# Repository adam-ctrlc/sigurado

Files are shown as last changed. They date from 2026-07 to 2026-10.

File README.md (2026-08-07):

# Sigurado

**Two scans. One person. No mystery.**

Sigurado is a dual-biometric access and materials accountability system for a school
laboratory stockroom. A fingerprint at the door opens a short window; the cabinet then
opens only for that same person, while that window is still live. Everything is recorded
with an identity, a reader, and a server timestamp, and shown on a live web console.

The name is Filipino for "sure", which is the point: at any moment you can say who opened
the cabinet and what they took.

---

## Why it works this way

Most fingerprint locks answer one question: is this a registered finger? That still lets a
stranger walk in behind somebody and open the cabinet a minute later. Sigurado answers a
harder one: **is this the person who just came through the door?**

1. **Scan at the door.** The lock releases and a timed window opens, belonging to one
   person.
2. **Scan at the cabinet, inside that window.** The reader checks that the finger it just
   read belongs to the person the door let in. Anything else is refused and recorded as a
   tailgating attempt.
3. **Record what you took.** The cabinet shows a one-time code on its screen as it opens.
   The website will not accept a checkout without that code, so a written record always
   corresponds to a real, physical opening.

The system separates two kinds of fact and never confuses them. **Reader events** come
from the hardware and cannot be edited by anyone, including an administrator.
**Checkouts** are claims typed in by a person, trustworthy only because they require the
code from the opening. The gap between the two is where the interesting questions live,
which is what the flags page is for.

## What it does

- **Sequential dual biometrics.** Door then cabinet, with a session that belongs to one
  person and expires on its own.
- **Enrollment with claiming.** A reader captures a fingerprint and shows a one-time code.
  The finger belongs to nobody until somebody enters that code on the website, so a
  template can never be silently bound to the wrong account.
- **Materials checkout.** An item and quantity table, an optional photo, and the cabinet's
  code as proof the opening happened.
- **Live audit trail.** Every scan, unlock, refusal and enrollment, streamed over
  server-sent events, searchable and filterable from the address bar.
- **Flags.** Eleven checks run over the trail and surface what does not add up: an opening
  with no record behind it, tailgating, guessed checkout codes, unregistered fingers tried
  repeatedly, openings outside lab hours, disabled accounts still trying, readers that have
  gone quiet, enrollment codes nobody ever claimed, and more.
- **Sheet.** The whole trail as a spreadsheet, with lettered columns, numbered rows, a
  frozen header and CSV export. Optionally mirrored to Google Sheets.
- **SMS alerts.** A SIM800L on the cabinet node sends a text when the cabinet opens or
  access is refused. The server queues; the node sends.
- **Roles.** Students see their own records, faculty see everything and change nothing,
  administrators run the room. An administrator cannot disable, delete or demote
  themselves.
- **Guides.** Numbered, step-by-step instructions built into the app for each role.

## Repository layout

```
backend/     Rust API: axum 0.8, SeaORM 1.1, SQLite, JWT, argon2
frontend/    SvelteKit 2 + Svelte 5 runes, Tailwind CSS v4, shadcn-svelte
esp32/       Firmware for both reader nodes (Arduino, ESP32 DevKit v1)
visualize/   Parametric OpenSCAD model of the cabinet and the scanner enclosure
```

## Hardware

Two ESP32 nodes, one at the door and one on the cabinet. Nothing exotic.

| Part | Notes |
| --- | --- |
| ESP32 DevKit v1, 30-pin | One per node. PSRAM and JTAG disabled in the IDE. |
| R307 or AS608 fingerprint sensor | One per node, on UART2. Templates live on the sensor. |
| 16x2 I2C LCD | Prompts, and the checkout code on the cabinet node. |
| Relay plus 12V solenoid | Fail-secure; the coil never runs off the ESP32 rails. |
| Lever limit switch | Reports whether the door is really shut. Debounced in firmware. |
| SIM800L | Cabinet node only, on UART1, with its own 4V supply. |
| Buzzer, LED, push button | Enrollment and the door-left-open reminder. |

Wiring for each node is documented at the top of its sketch. Matching is done on the
sensor itself, so slot numbers are local to a reader; that is why a person enrolls at the
door and at the cabinet separately, and why finger tokens are namespaced per device.

If the door node cannot reach the router, the cabinet node can share its connection:
set `SHARE_WIFI` in the cabinet config and point the door node at its SSID.

## Running it

### Backend

```bash
cd backend
cp .env.example .env          # then fill in DATABASE_URL and JWT_SECRET
cargo run -p migration -- up  # migrations do not run at startup
cargo run --bin seed          # creates the first administrator
cargo run --bin backend
```

Listens on `127.0.0.1:8080` by default. The SQLite file lives in `backend/db/`,
which is where `.env.example` points and the only place worth backing up. The
server creates that folder if it is missing, so pointing `DATABASE_URL` somewhere
new needs no `mkdir` first.

### Frontend

```bash
cd frontend
pnpm install
pnpm dev
```

Serves on `localhost:5173` and expects the API at `localhost:8080`.

### Firmware

Open `esp32/door/door.ino` or `esp32/cabinet/cabinet.ino` in the Arduino IDE. Board:
**ESP32 Dev Module**. Libraries: Adafruit Fingerprint Sensor Library, LiquidCrystal I2C,
ArduinoJson v7. Pair each node from **Devices** in the web app, then paste the device id
and secret it gives you into `src/Config.h`. The secret is shown once.

Both sketches compile clean against esp32 core 3.3.11, at roughly 81% of the default
1.2MB app partition.

## Configuration

All backend settings live in `backend/.env`; see `.env.example`. Notable ones:

| Variable | Default | What it does |
| --- | --- | --- |
| `SESSION_TTL_SECS` | 120 | How long the door window stays open. |
| `ENROLL_CODE_TTL_SECS` | 300 | Life of an enrollment code. |
| `LAB_UTC_OFFSET_HOURS` | 8 | The room's clock, used for after-hours checks and dates. |
| `SHEETS_ENABLED` | false | Optional mirror of the trail into Google Sheets. |

Values containing spaces must be quoted. Anything after an unquoted space is silently
dropped by the parser, which is a good way to lose an afternoon.

## Security notes

- Passwords are hashed with argon2. The policy is 8 to 16 characters with an upper, a
  lower and a symbol, enforced in the backend and mirrored in the UI.
- Readers authenticate with a device id and secret pair, never a user token, so a stolen
  reader cannot impersonate a person. Secrets can be rotated from the web app.
- Fingerprint templates never leave the sensor. The server only ever sees an opaque token.
- Reader events cannot be edited or deleted through the API by anyone. A wrong record is
  corrected by adding the right one.
- `.env` files, the database, and uploaded photos are excluded from version control. Every
  credential in the repository is a placeholder.

## Status

Backend, frontend and firmware are complete and build clean, with the backend test suite
and `svelte-check` passing. The firmware compiles for the ESP32 but has not been run on
assembled hardware yet, so treat pin assignments and timings as correct-but-unproven until
you have flashed a board. The SMS and Google Sheets paths were verified end to end against
local stand-ins rather than a real modem or a real Google account.

## License

Apache License 2.0. See [LICENSE](LICENSE).

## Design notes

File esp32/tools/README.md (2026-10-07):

# Tools

Double-click the `.cmd` files. Each one is a thin wrapper that runs the matching
PowerShell script in `scripts/` with the execution policy bypassed for that one
call, so nothing has to be changed machine wide.

| File | What it does |
|---|---|
| `Find-Board.cmd` | Lists the boards it can see and says why each port was picked |
| `Upload-Door.cmd` | Compiles and flashes `door/` |
| `Upload-Cabinet.cmd` | Compiles and flashes `cabinet/` |
| `Monitor-Door.cmd` | Serial monitor on the door node |
| `Monitor-Cabinet.cmd` | Serial monitor on the cabinet node |

Both uploaders take an optional sketch name to send one of the component tests
in `testing/` instead of the firmware:

```
Upload-Door.cmd fingerprint
Upload-Cabinet.cmd limit_switch
```

## Finding the right board

You never type a COM number. `Find-Board.ps1` reads the USB vendor and product
id behind every serial port and only considers the chips an ESP32 board actually
uses: CP210x, CH340, CH9102, FTDI, and Espressif's own native USB. A laptop with
a paired phone has two or three Bluetooth COM ports that look like boards to
anything that only counts ports, and those are excluded.

The door and cabinet nodes are the same hardware, so USB cannot tell them apart.

- One board plugged in: it is taken as whichever node you asked for.
- Two plugged in, and one already known: the other is deduced, no question asked.
- Two plugged in and neither known: you are asked once, and the answer is saved
  in `scripts/nodes.json` against the board's USB instance id, so it survives
  Windows renumbering the ports.

`nodes.json` is local to your machine and is not committed. Delete it, or run
`scripts\Find-Board.ps1 -Node door -Forget`, to be asked again.

## Requirements

`arduino-cli` on the PATH:

```
winget install ArduinoSA.CLI
```

then the board support and the three libraries:

```
arduino-cli core install esp32:esp32
arduino-cli lib install "Adafruit Fingerprint Sensor Library"
arduino-cli lib install "LiquidCrystal I2C"
arduino-cli lib install ArduinoJson
```

## Notes

The board is **DOIT ESP32 DEVKIT V1**, FQBN `esp32:esp32:esp32doit-devkit-v1`.
It has no PSRAM or JTAG entries in the Tools menu, so there is nothing there to
turn off. Those options only appear for the S3 boards.

Uploading starts at 921600 baud and retries once at 115200 if that fails, which
is the usual fix on a CH340 with a long lead rather than anything to do with the
wiring.

A monitor window holds the port open, and an upload cannot then claim it. Close
it with Ctrl+C first. If an upload fails part way through, that is the first
thing to check.

Run any script directly for the full help:

```
Get-Help .\scripts\Find-Board.ps1 -Full
```

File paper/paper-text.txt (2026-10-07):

Sigurado: A Dual-Biometric Sequential Access and Materials
Accountability System for a Laboratory Stockroom

Gerjhon Aballa, John Lloyd Abragan, and John Adam A. Cuenca
Department of Computer Engineering
CPE 048: Embedded Systems — COC-FA-CPE4-01
[INSTRUCTOR NAME]
[DUE DATE]

Contents
CHAPTER 1: INTRODUCTION

1

1.1 Background of the Study . . . . . . . . . . . . . . . . . . . . .

1

1.2 Statement of the Problem . . . . . . . . . . . . . . . . . . . . .

3

1.3 Objectives of the Study . . . . . . . . . . . . . . . . . . . . . .

4

1.4 Significance of the Study . . . . . . . . . . . . . . . . . . . . .

5

1.5 Scope and Limitations

. . . . . . . . . . . . . . . . . . . . . .

7

1.6 Definition of Terms . . . . . . . . . . . . . . . . . . . . . . . . .

8

CHAPTER 2: SYSTEM DESIGN

10

2.1 System Overview . . . . . . . . . . . . . . . . . . . . . . . . .

10

2.2 System Architecture . . . . . . . . . . . . . . . . . . . . . . . .

11

2.2.1 Overall System Architecture . . . . . . . . . . . . . . .

11

2.2.2 Microcontroller Architecture . . . . . . . . . . . . . . . .

11

2.2.3 Memory Architecture . . . . . . . . . . . . . . . . . . .

12

2.2.4 Input and Output Architecture . . . . . . . . . . . . . .

13

2.2.5 Communication Architecture . . . . . . . . . . . . . . .

14

2.3 Block Diagram . . . . . . . . . . . . . . . . . . . . . . . . . . .

15

2.4 Hardware Components . . . . . . . . . . . . . . . . . . . . . .

15

2.5 Hardware Architecture Design . . . . . . . . . . . . . . . . . .

16

2.6 What a Person Sees at the Reader . . . . . . . . . . . . . . .

18

2.7 The Web Console . . . . . . . . . . . . . . . . . . . . . . . . .

20

2.7.1 The Public Page . . . . . . . . . . . . . . . . . . . . . .

20

2.7.2 What Each Role Sees . . . . . . . . . . . . . . . . . . .

21

2.7.3 The Record . . . . . . . . . . . . . . . . . . . . . . . .

22

2.7.4 On a Phone . . . . . . . . . . . . . . . . . . . . . . . .

23

i

2.8 Data Flow . . . . . . . . . . . . . . . . . . . . . . . . . . . . .

24

2.8.1 Steps in One Complete Use . . . . . . . . . . . . . . .

25

2.8.2 How the Chip Runs the Instructions . . . . . . . . . . .

26

CHAPTER 3: TESTING AND PERFORMANCE

27

3.1 Unit and Integration Testing . . . . . . . . . . . . . . . . . . . .

27

3.2 System Testing . . . . . . . . . . . . . . . . . . . . . . . . . .

28

3.2.1 Testing the Assembled Readers . . . . . . . . . . . . .

28

3.3 Test Results . . . . . . . . . . . . . . . . . . . . . . . . . . . .

29

3.4 System Requirements

. . . . . . . . . . . . . . . . . . . . . .

31

3.5 Performance Analysis . . . . . . . . . . . . . . . . . . . . . . .

33

3.5.1 Use of Chip Resources . . . . . . . . . . . . . . . . . .

33

3.5.2 Timing . . . . . . . . . . . . . . . . . . . . . . . . . . .

33

3.5.3 Comparison With Published Systems . . . . . . . . . .

34

CHAPTER 4: CONCLUSION

36

4.1 Problems Encountered . . . . . . . . . . . . . . . . . . . . . .

36

4.1.1 Slot Numbers Meant Different People . . . . . . . . . .

36

4.1.2 A Reader Cannot Be Trusted to Decide . . . . . . . . .

36

4.1.3 One Unknown Record Emptied the Whole Page . . . .

36

4.1.4 Settings Were Cut Without Warning . . . . . . . . . . .

36

4.1.5 Electrical Problems That Only Appear in Hardware

. .

37

. . . . . .

37

4.2 Troubleshooting . . . . . . . . . . . . . . . . . . . . . . . . . .

37

4.2.1 Finding the Empty Page Fault . . . . . . . . . . . . . .

37

4.2.2 Always Start With Something That Works . . . . . . . .

38

4.2.3 Checking Code Before Flashing . . . . . . . . . . . . .

38

4.1.6 The Door Reader May Not Reach the Wi-Fi

ii

4.3 Solutions and Conclusions . . . . . . . . . . . . . . . . . . . .

38

4.3.1 What We Fixed . . . . . . . . . . . . . . . . . . . . . .

38

4.3.2 Conclusion . . . . . . . . . . . . . . . . . . . . . . . . .

39

4.3.3 Recommendations . . . . . . . . . . . . . . . . . . . .

40

iii

List of Figures
1

How the parts connect.

. . . . . . . . . . . . . . . . . . . . .

11

2

Inside one reader. Dashed boxes are parts outside the chip.

15

3

The cabinet with its service panel removed, showing the
electronics bay above the materials bins . . . . . . . . . . . .

4

Inside the reader box with the back plate removed, showing
the board, sensor, relay and lock wiring . . . . . . . . . . . .

5

22

The trail as a spreadsheet, with grants and refusals in the
same list . . . . . . . . . . . . . . . . . . . . . . . . . . . . . .

8

21

The administrator dashboard, showing live sessions and the
decisions as they arrive . . . . . . . . . . . . . . . . . . . . .

7

18

The public page, which explains the system without exposing
any record . . . . . . . . . . . . . . . . . . . . . . . . . . . . .

6

17

23

The site on a phone: the public page, the dashboard, and the
checkout form where the one-time code is entered . . . . . .

iv

24

List of Tables
1

How the chip uses its memory

. . . . . . . . . . . . . . . . .

13

2

What is connected to which pin . . . . . . . . . . . . . . . . .

14

3

Parts used and what each one does . . . . . . . . . . . . . .

16

4

What the door reader displays

. . . . . . . . . . . . . . . . .

19

5

What the cabinet reader displays . . . . . . . . . . . . . . . .

20

6

What we tested and what happened . . . . . . . . . . . . . .

30

7

What the system must do . . . . . . . . . . . . . . . . . . . .

32

8

Timings we set, and timings still to be measured . . . . . . .

34

v

CHAPTER 1: INTRODUCTION
1.1 Background of the Study
Schools lend laboratory equipment to their students and staff, and
keeping track of what has gone out is a recognised management problem
(Cepeda & Saludes, 2025).

Cepeda and Saludes (2025) examined

equipment lending at a Philippine university and reported that handling the
process by hand left the institution weak in three areas at once: operational
efficiency, data accuracy, and accountability. Those three weaknesses are
the reason such institutions move to recorded, automated lending (Cepeda
& Saludes, 2025). The gap survives because entry to a room and the
record of what left it are governed by two separate mechanisms that never
verify one another (Cepeda & Saludes, 2025).
Records maintained by hand also drift away from the physical stock
they are meant to describe (Linuwih & Handayati, 2025). Linuwih and
Handayati (2025) counted stock against the written record in a warehouse
and found that 52.85 percent of product types did not match during a single
stocktake. A written record that disagrees with the shelf in more than half of
cases cannot settle a question about who holds what (Linuwih & Handayati,
2025). Physical keys carry a separate weakness of their own (Alrawili
et al., 2024). Alrawili et al. (2024) observe that anything a person carries,
as opposed to something a person is, can be handed to somebody else. A
key is therefore able to be lent, copied, or lost, after which the lock records
only that somebody held a key rather than who that person was (Alrawili
et al., 2024).
Biometric identification answers that weakness directly, because a
fingerprint belongs to the person rather than being carried by them (Alrawili
1

et al., 2024). Alrawili et al. (2024) reviewed how such systems are chosen
and found that the choice is always a balance. A system has to be secure,
but it also has to be convenient and robust, or it will not survive contact with
the people who use it (Alrawili et al., 2024). Fingerprints sit at a workable
point on that balance, being inexpensive to read and quick enough to
complete a scan in roughly one second on low-cost hardware (Alsayaydeh
et al., 2025).
Fingerprint locks built on low-cost microcontrollers are now a well
documented application of this hardware (Rahman et al., 2026). Alsayaydeh
et al. (2025) built one using an ESP32, a small computer chip with built-in
Wi-Fi. Their lock read a finger in roughly one second and released the door
about five seconds later (Alsayaydeh et al., 2025). It admitted the wrong
person 1.32 percent of the time, which is a good result (Alsayaydeh et al.,
2025). It also turned away the right person 26.32 percent of the time, so
nearly one legitimate user in four had to present a finger again (Alsayaydeh
et al., 2025). That rejection figure is the convenience side of the balance
described by Alrawili et al. (2024), on which a system that is not convenient
will not survive contact with its users.
A single reader also carries a limit that no improvement in sensor
accuracy can remove, since one reader verifies only the credential
presented to it and nothing about the person who may have entered
alongside its user (Mohammed et al., 2025). Researchers have answered
this by verifying a person more than once rather than by trying to perfect a
single check (Mohammed et al., 2025). Mohammed et al. (2025) tested a
system built this way and measured a 68 percent drop in fraudulent access.
The gain came from requiring more than one independent confirmation
2

before granting entry, not from a more accurate sensor (Mohammed et al.,
2025). Their framework still answered in 235 milliseconds on average, so
the extra check did not make the system slow (Mohammed et al., 2025).
The record itself must also resist alteration, since a saved list is only
useful if nobody can revise it after an incident (Koisser & Sadeghi, 2023).
Koisser and Sadeghi (2023) studied this problem across connected devices
and describe tampering as the central weakness of digital records, which is
why their scheme is built to make any modification detectable rather than
merely discouraged. Read together, these findings describe one design:
verify a person twice and bind the second check to the first (Mohammed et
al., 2025), then hold the result where it cannot be edited (Koisser & Sadeghi,
2023).
1.2 Statement of the Problem
A school stockroom cannot prove who took its materials, because
the accountability its records are meant to provide is precisely what manual
handling fails to deliver (Cepeda & Saludes, 2025).

Two weaknesses

produce this failure. A single reader verifies only the credential presented
to it, so a person admitted alongside an authorized user is never evaluated
and never recorded, which is the weakness Mohammed et al. (2025)
address by requiring more than one confirmation. Written records then
disagree with the physical stock they describe in more than half of the
product types examined (Linuwih & Handayati, 2025), and moving those
records onto a computer does not repair the problem, since a list that can
still be revised afterwards carries the same weakness as a paper one
(Koisser & Sadeghi, 2023). The institution is therefore left unable to show
either that its list of names is complete or that nothing on it was altered
3

later, which are the two properties an accountable record requires (Koisser
& Sadeghi, 2023; Linuwih & Handayati, 2025).
Specifically, this study seeks to answer the following questions:
1. How can an access system be designed so that the cabinet opens only
for the same person who opened the door, and refuses anyone who
followed that person in?
2. How long should a door session stay open, and how can it be closed
automatically once that time has passed?
3. How can every scan, whether allowed or refused, be stored so that no
user is able to edit or delete it afterwards?
4. How can a written record of borrowed items be tied to a real, physical
opening of the cabinet?
5. How do the processors, memory, pins, and Wi-Fi of the ESP32 chip
support each of these functions?
6. Does the finished program behave as intended in testing, and does it
fit within the memory of the chip with room left over?
1.3 Objectives of the Study
The general objective of this study is to design and build an
embedded system that can prove who took materials from a school
stockroom, and can store that proof in a form that nobody is able to change
afterwards.
The specific objectives below answer the six questions above, in the
same order. Each objective states what the study will build or measure in
order to settle the matching question.
4

1. To require two finger scans in order, one at the door and one at the
cabinet, and to open the cabinet only for the same person who opened
the door.
2. To close the door session automatically after 120 seconds, a value
taken from the 2 to 5 minute idle timeout that OWASP Foundation
(2026) recommend for high-value applications, so that an unattended
door does not stay usable.
3. To save every scan, whether allowed or refused, in a record that no
user can edit or delete.
4. To require a one-time code, shown on the cabinet screen as it opens,
before the system will accept a list of borrowed items.
5. To document how the processors, memory, pins, and Wi-Fi of the
ESP32 chip support each of these functions.
6. To test the finished software and confirm that the program fits within
the memory of the chip with room left over.
1.4 Significance of the Study
This study is useful to the groups described below.
Students. Students who borrow equipment gain a fair and complete
record. Because every scan is saved with a name and a time, a student
cannot easily be blamed for something that somebody else removed. The
record protects the borrower just as much as it protects the school, and it
removes the argument that so often follows a missing item. Students also
gain a faster way of borrowing, since there is no notebook to find and no
queue behind the person writing in it.
5

Teachers and laboratory staff. Staff no longer need to read other
people’s handwriting or chase students for entries that were never made.
The list builds itself as people use the room, and it can be searched in
seconds rather than flipped through page by page. Staff can also see at
a glance whether a reader has stopped working, instead of discovering it
only when something goes wrong.
Stockroom custodians and administrators. Administrators gain
something a notebook can never provide, which is proof. When an item
goes missing they can see exactly who opened the cabinet, at what time,
and what was logged against that opening. This speaks directly to the
record inaccuracy measured by Linuwih and Handayati (2025), where more
than half of the product types checked disagreed with their written record.
Administrators can also see refused attempts, which reveals whether people
are trying to enter when they should not be. That second view turns a vague
worry about losses into a number that can be watched over time.
The school. Laboratory equipment is expensive and school budgets
are limited. Better records mean fewer unexplained losses, and they support
better decisions about what needs replacing and how much to buy. Over
several terms, the record also shows which items are used heavily and which
sit untouched.
Future researchers. This study documents what worked and what
did not, including a fault discovered during testing and the measurements
still to be taken. Other students can reuse the design, extend it to more
rooms, or take the honest account of its limits as a starting point and avoid
repeating the same mistakes.

6

1.5 Scope and Limitations
This study covers one door and one storage cabinet inside a single
school stockroom, served by two reader units and one server. A server is
the computer that stores all the records and makes the decisions about who
may enter. The system handles signing up a fingerprint, the two scans,
the borrowing record, the saved history, and text message alerts. It also
shows different information to students, teachers, and administrators, so that
a student sees only their own records while an administrator sees everything.
The study carries the following limits, and every claim made later in
this paper should be read against them.
1. Performance was not measured in numbers.

Both readers

were built, wired, flashed and exercised through the complete
door-to-cabinet sequence, so the system is demonstrated to work.
What the study does not provide is quantitative performance data:
scan time, unlock time and error rates were not recorded over a
controlled set of trials, so no such figure is claimed here.
2. The sensor does the matching.

Fingerprints are stored and

compared inside the sensor itself, never on our chip. The system is
therefore only as accurate as the sensor, and it has no way of telling
a real finger from a fake one. Rad et al. (2024) showed that copies
made from seaweed jelly can fool this kind of sensor.
3. People must sign up twice. Once at the door and once at the cabinet,
because each sensor keeps its own separate list of fingers.
4. The borrowed list is still typed by a person. The system can prove
7

that the cabinet opened and who opened it. It cannot check whether
the list of items typed afterwards is complete or honest.
5. Text messages were not sent over a real network. They were tested
using a stand-in program on the computer rather than a real SIM card
and a real phone line.
6. One room only. The design was not tested across several rooms or
with several cabinets running at the same time.
1.6 Definition of Terms
The terms below are listed in alphabetical order and are defined as
they are used in this study.
Audit trail The saved list of every scan and every decision the system has
made.
Embedded system A small computer built into a device to do one particular
job.
ESP32 The chip used in this project. It is a small computer with built-in WiFi.
Fingerprint sensor The part that reads a finger and compares it against a
list stored inside itself.
Memory Space inside the chip that holds the program and the data it is
working on.
Relay An electric switch that lets a small chip control a much stronger power
supply.
8

Server The main computer that keeps every record and decides who may
enter.
Session A short time window, 120 seconds in this study, that opens when
somebody scans at the door.
Solenoid lock An electric lock that opens while power is sent to it and locks
again when the power stops.
Tailgating Walking into a room behind somebody who has just opened the
door, without scanning a finger.

9

CHAPTER 2: SYSTEM DESIGN
2.1 System Overview
The system has three parts: a reader at the door, a reader at the
cabinet, and one server. Each reader is an ESP32 chip with a fingerprint
sensor, a small screen, and an electric lock.
The readers never decide anything by themselves. When someone
scans a finger, the sensor finds a match and gives back a slot number.
The reader sends that number to the server. The server decides, saves
the result, and sends back a yes or no.
This matters because a reader hangs on a wall where anyone can
reach it. If a reader could decide on its own, someone could open it and fool
it. The server sits in a locked place, so the decision stays safe.
Access happens in two steps. A finger at the door unlocks the door
and starts a 120-second session for that one person. A finger at the cabinet
opens it only if it belongs to the same person, and only while the session is
still running. A registered finger with no session is refused, and the refusal
is saved. This is the double check that Mohammed et al. (2025) found cuts
fake entries.
The 120-second figure is not arbitrary. OWASP Foundation (2026)
recommend an idle timeout of 2 to 5 minutes for high-value applications,
against 15 to 30 minutes for low-risk ones, and a stockroom of shared
equipment belongs in the first group. We took the strictest end of that
range. Two minutes is long enough to cross a room and reach the cabinet,
and short enough that a person who walks away leaves nothing useful
behind them.
When the cabinet opens, it shows a one-time code on its screen.
10

The website will not accept a borrow record without that code. So every
written record matches a real opening. Reader records can never be edited
or deleted. This is the protection Koisser and Sadeghi (2023) say a log
needs.
2.2 System Architecture
The architecture is described at five levels. The first covers how the
separate parts connect to one another. The four that follow look inside a
single reader, at its processor, its memory, the pins it uses to reach the
outside world, and the network it speaks over.
2.2.1 Overall System Architecture
Figure 1 shows how the parts connect. Both readers talk to the server.
They never talk to each other. The dashed line is a backup: if the door reader
cannot reach the Wi-Fi, the cabinet reader can share its connection.
Figure 1
How the parts connect.
Door reader
ESP32, sensor,
screen, lock
backup Wi-Fi

Cabinet reader

Server

Website

keeps records,

for people

makes decisions

to use

ESP32, sensor, screen,
lock, buzzer, SIM800L

2.2.2 Microcontroller Architecture
Both readers use the ESP32. The chip carries two processors, each
able to run at up to 240 MHz, and is rated at 1079.96 CoreMark in that
11

configuration (Espressif Systems, 2025). Rahman et al. (2026) reviewed the
platform and identified the combination of dual-core processing, integrated
radios and peripheral support as its principal strength, while naming limited
on-chip memory and real-time constraints as its standing weaknesses.
The second processor is what makes the workload here practical.
The fingerprint sensor is slow relative to the processor, so one core can wait
on the sensor while the other holds the network connection open.
2.2.3 Memory Architecture
The chip provides 448 KB of ROM for start-up code, 520 KB of onchip RAM for running programs, and two smaller low-power regions of 8
KB each, with the application image held in external flash and executed
through a cache (Espressif Systems, 2025). Limited on-chip memory is the
constraint Rahman et al. (2026) single out as the platform’s most persistent
difficulty.
Table 1 shows how this project uses those regions. Our program fills
about 81 percent of the 1.2 MB partition set aside for it, which leaves room
to grow but not a great deal of it.
One design choice removes the memory pressure that Rahman et al.
(2026) describe. Fingerprints are never stored on our chip; they stay inside
the sensor, which returns only a slot number. Fingerprint data is the largest
structure the reader would otherwise hold, so leaving it on the sensor keeps
the 520 KB of RAM (Espressif Systems, 2025) comfortable rather than tight.

12

Table 1
How the chip uses its memory

Storage Size

What we use it for

ROM

Start-up code.

448 KB

We do not

change it.
RAM

520 KB

The running program and its
working data.

Flash

1.2 MB

Our program. About 81% full.

Sensor

Inside sensor

Fingerprints.

Our chip never

reads them.

2.2.4 Input and Output Architecture
The chip exposes 34 programmable pins, three serial ports capable
of up to 5 MBaud, two I2C interfaces and four SPI controllers (Espressif
Systems, 2025). Sigurado uses three of those classes and leaves SPI
unused.
Table 2 lists what we connected where.

The fingerprint sensor

is given its own serial port because it exchanges packet messages
continuously. The screen uses I2C, which carries a display on two wires
(Espressif Systems, 2025). The lock, button, and light need only single
pins.

13

Table 2
What is connected to which pin

Part

Connection

Door

Cabinet

Fingerprint sensor

Serial port 2

16, 17

16, 17

Screen

I2C

21, 22

21, 22

Sign-up button

Pin (in)

4

4

Status light

Pin (out)

2

2

Lock switch

Pin (out)

5

5

Door closed sensor

Pin (in)

—

18

Buzzer

Pin (out)

—

19

Text message unit

Serial port 1

—

26, 27, 25

The lock pin is the only one that moves something physical. The lock
runs on its own 12 V power, not from the chip. A relay acts as the switch
between them. The lock stays open for 3 seconds. The cabinet also has a
small switch that tells us whether the door really closed.
2.2.5 Communication Architecture
Each reader joins the school Wi-Fi and sends messages to the server.
Each reader has its own ID and password. It does not use a person’s login.
This matters. If someone steals a reader and opens it, they only get
that reader’s password. They cannot pretend to be a person, and we can
change that one password without touching the other reader. Rahman et al.
(2026) name security setup as a common weak spot on this chip, and this
is what it looks like in practice.
Each reader also says “I am still here” every 30 seconds. That is how
14

the website shows which readers are working. All clocks are set from the
internet, so every record has a matching time.
2.3 Block Diagram
Figure 2 shows the inside of one reader and what connects to it.
Figure 2
Inside one reader. Dashed boxes are parts outside the chip.
Server

Wi-Fi
I2C
Two processors

Screen
Fingerprint

Serial 2
240 MHz

sensor
Lock, light,
Pins

Memory

button, buzzer
Text unit

Serial 1

(cabinet only)

2.4 Hardware Components
Table 3 lists every part used and the job it does. Quantities are per
reader unless the entry says otherwise. Nothing on the list is rare or difficult
to source, which was deliberate. A part that cannot be replaced from a local
shop is a part that ends the project on the day it fails.

15

Table 3
Parts used and what each one does

Part

What it does

ESP32 board

The small computer. Runs the program
and connects to Wi-Fi. One per reader.

Fingerprint

Reads a finger and checks it against its

sensor (R307 or

own stored list. Fingerprints never leave

AS608)

it.

Small screen (16

Shows messages. On the cabinet it also

by 2)

shows the one-time code.

Relay and 12 V

The relay is a switch. The lock runs on its

lock

own power, not the chip’s.

Door switch

Cabinet only. Tells us if the door really
closed.

SIM800L text unit

Cabinet only.

Sends a text when the

cabinet opens or someone is refused.
Buzzer,
button

light,

The button starts sign-up.

The buzzer

warns if the door is left open.

2.5 Hardware Architecture Design
The cabinet and the reader box were drawn as 3D models before
building.

The cabinet has three shelves behind locked doors. All the

electronics sit in a hidden space behind a screwed panel, so users never
see them.

16

Figure 3
The cabinet with its service panel removed, showing the electronics bay
above the materials bins

Figure 4 looks inside the reader box itself, with the back plate taken
off. This is the view used to check that every part fits and to plan the wiring
before anything was cut.

17

Figure 4
Inside the reader box with the back plate removed, showing the board,
sensor, relay and lock wiring

Wiring follows Table 2. Three rules guide the layout. First, the lock
gets its own power supply, because it pulls a lot of current when it opens
and would otherwise restart the chip. Second, the text unit also gets its own
supply, for the same reason. Third, one wire on the text unit needs a voltage
reducer, because the chip’s signal is too strong for it.
2.6 What a Person Sees at the Reader
The person standing at the door has one screen and two lines of
sixteen characters to work with. That limit shapes every message: there is
no room to explain, so each line has to say one thing. The wording below is
taken from the firmware exactly as it is displayed.
Table 4 lists what the door reader shows. When nothing is happening

18

it rests on its idle message, so anybody walking up already knows what to
do without being told.
Table 4
What the door reader displays
Situation

Top line

Bottom line

Waiting for anyone
Finger on the sensor
Asking the server
Allowed in
Finger not signed up
Bad read

Sigurado door
Reading
Checking...
Welcome
Not registered
Did not read

Signing up a finger
No network

the code
No WiFi yet

Scan finger
hold still
one moment
their name
Press enroll
please try
again
Type it on site
check settings

The cabinet reader carries the harder messages, because it is the one
that says no. Table 5 shows those. The two refusals are worded differently
on purpose. Scan door first means the person never came through the
door, which is the tailgating case. Scan door again means they did, but took
longer than the session allowed. Telling those apart on the screen saves the
person guessing what went wrong.

19

Table 5
What the cabinet reader displays
Situation

Top line

Bottom line

Allowed in
The one-time code
Where to type it
Cabinet open

Unlocked
Your code
Type it on the
Take what you

No door scan
Session ran out
Door left open
Door shut again
Text alert going out

Still locked
Still locked
Door is open
Door closed
Sending alert

their name
the code
checkout page
need, then
close
Scan door first
Scan door again
Please close it
Thank you
please wait

A refused person is never left without an instruction. Every refusal
names the thing to do next, because a screen that only says no teaches
people to rattle the handle instead.
2.7 The Web Console
The readers handle the locks. Everything a person reads, types, or
checks happens on the website. It runs in an ordinary browser and talks to
the same server the readers do, so the console never sees a reader directly
and cannot open anything itself.
2.7.1 The Public Page
Figure 5 shows what a visitor sees before signing in. It explains the
two-scan rule and nothing else. There is no public list of people, no record
of any opening, and no way in except the sign-in link. Accounts are created
by an administrator, so there is no sign-up form to attack.

20

Figure 5
The public page, which explains the system without exposing any record

2.7.2 What Each Role Sees
Signing in decides what the rest of the site shows. A student sees
only their own scans and their own borrowed items. A member of faculty
sees everything but can change nothing. An administrator runs the room:
accounts, readers, alerts, and the stored data. The rule the site enforces is
that a student must never see another student’s record, and that nobody at
all can edit a reader event.
Figure 6 shows the administrator view. The four counters along the
top answer the question a custodian actually asks on walking in: is anyone
inside the window right now, how many scans have happened today, how
many were refused, and how much was taken. Below them sit the live door
sessions, each with its own countdown, and the stream of decisions as they

21

arrive.
Figure 6
The administrator dashboard, showing live sessions and the decisions as
they arrive

2.7.3 The Record
Figure 7 shows the trail as a spreadsheet. Every row is something
a reader reported: a door opened, a cabinet unlocked, a finger refused, an
enrollment code issued. Each carries the time, the person where one is
known, the finger slot, and the reader that saw it. Refusals sit in the same
list as grants, which is what makes a tailgating attempt countable rather than
invisible.

22

Figure 7
The trail as a spreadsheet, with grants and refusals in the same list

The same page exports to CSV, so the record can be kept outside
the system as well. The console also runs eleven checks over the trail and
lists whatever does not add up: an opening with no borrow record behind it,
a finger tried repeatedly and refused, an opening outside laboratory hours,
a reader that has gone quiet. These are the questions a person would have
to ask by hand if the record were on paper.
2.7.4 On a Phone
Most people will reach the site on a phone, standing at the cabinet
with the one-time code still on the screen in front of them. The whole console
is built to work at that size, not just to survive it. Figure 8 shows three of those
screens.

23

Figure 8
The site on a phone: the public page, the dashboard, and the checkout
form where the one-time code is entered

Three things change on a small screen. The side menu folds away
behind a button, so the content gets the full width. The counters stack
instead of sitting in a row. The record tables scroll sideways rather than
shrinking their text, because a column of times squeezed to four characters
is worse than one the reader has to push across.
2.8 Data Flow
This section follows one complete use of the system twice. The first
pass describes it as a sequence of events a person in the room would
recognise. The second describes the same sequence as the work the
processor actually performs.

24

2.8.1 Steps in One Complete Use
The sequence below traces one successful use from beginning to
end, from the first finger at the door to the borrowed items appearing in the
record.
1. Someone puts a finger on the door sensor. The sensor finds a match
and gives back a slot number.
2. The door reader sends that number, plus its own ID and password, to
the server.
3. The server looks up the person, starts a 120-second session, saves
the record, and replies “allowed”.
4. The door reader opens the lock for 3 seconds and shows a message.
5. Someone puts a finger on the cabinet sensor. The cabinet reader
sends its own request.
6. The server checks whether this is the same person who has the
running session. If yes, it makes a one-time code and saves the
record. If no, it refuses and saves that too.
7. The cabinet opens, shows the code, and queues a text message. If
the door is left open, the buzzer sounds.
8. The person types the code and the borrowed items into the website.
The server accepts it only if the code is still valid.

25

2.8.2 How the Chip Runs the Instructions
Underneath, the chip repeats the same cycle over and over. It fetches
an instruction, works out what it means, and does it (Espressif Systems,
2025). Three moments show this clearly.
Waiting for the sensor. The chip checks the serial port again and
again to see whether a byte has arrived. Most of the time none has. This
is why we wrote the code so it never gets stuck waiting. If it did, the Wi-Fi
would drop.
Building the message. The chip copies text into memory, piece by
piece, to form the request. This is the step that uses the most memory.
Opening the lock. This is one instruction: send power to pin 5. After
that, the chip checks a timer on each loop. When 3 seconds have passed,
it sends one more instruction to switch the pin off. It never pauses, so it can
still handle other work in between.

26

CHAPTER 3: TESTING AND PERFORMANCE
Testing ran at three levels. Unit tests checked the decision logic on its
own. Integration tests checked that the website and the server agree with
each other. System tests exercised the assembled hardware end to end,
from a finger at the door to a borrowed item appearing in the record.
One limit applies to everything below. The tests establish that each
behaviour happens, not how fast or how reliably it happens over many
attempts. Timing and error rates were not recorded across a controlled set
of trials, so the rows marked [MEASURE] in Table 6 and Table 8 are left for
that work.
3.1 Unit and Integration Testing
Unit testing means checking small pieces of code one at a time. We
wrote 18 of these tests for the server, where the decisions are made. They
cover three things: that passwords follow the rules, that the warning checks
work on a quiet record as well as a busy one, and that the date maths is
right.
Integration testing means checking that two parts agree with each
other. The website is checked against the server automatically. That check
passed with no errors across 4,871 files. This catches the case where the
server starts sending something the website does not expect.
The reader firmware was compiled for the target board before
flashing.

Both programs built with no errors, which confirmed that the

modules link correctly and that the libraries match the board.

27

3.2 System Testing
System testing means using the whole thing the way a person would.
We ran the server and the website together against a database that already
held records. This matters. An empty database returns nothing, so a fault
that only appears with real data would stay hidden.
We logged in first, on purpose. It worked and returned the right
account. This proved the system was alive, so any later failure would mean
something real and not just a dead server.
Then we opened each page the website uses. The record list, the
borrow list, the active session check, and the live feed all worked. The record
list held 39 saved events of eight different kinds. All 20 pages of the website
loaded.
3.2.1 Testing the Assembled Readers
With both readers built and flashed, the complete sequence was
exercised on the hardware itself. A registered finger at the door released
the door lock and opened a session.

The same finger at the cabinet

released the cabinet within that session. The cabinet displayed its one-time
code, and the website accepted a borrow record only when that code was
entered.
The refusal paths were exercised as well, since a system that only
ever grants access has not been tested. A registered finger presented at
the cabinet without a door session first was refused, and the refusal was
written to the record as a tailgating attempt. A finger that had expired out of
its session was likewise refused. In both cases the cabinet stayed shut and
the attempt appeared in the trail with a name, a reader, and a time.

28

3.3 Test Results
Table 6 records the outcome of every activity described above,
together with the evidence behind it.

Rows marked [MEASURE] are

behaviours already shown to work whose performance has not yet been
quantified.

29

Table 6
What we tested and what happened
What we tested

Result

How we know

Software
Server unit tests
Website and server fit
Door reader build
Cabinet reader build
Logging in

Passed
Passed
Passed
Passed
Passed

Record list
Borrow list
Session check
Live feed
Website pages

Passed
Passed
Passed
Passed
Passed

18 tests, none failed
0 errors, 4,871 files
Compiled, no errors
Compiled, no errors
Correct
account
returned
39 events, 8 kinds
Records returned
Worked
Stayed connected
20 of 20 loaded

Assembled hardware
Door
scan
opens
session
Cabinet opens for same
person
One-time code shown
Borrow record needs
code
Tailgating refused

Passed
Passed
Passed
Passed
Passed

Expired session refused
Refusals recorded

Passed
Passed

Not yet quantified
Scan time

[MEASURE]

Unlock time

[MEASURE]

False acceptance rate

[MEASURE]

False rejection rate

[MEASURE]

Text messages

Stand-in only

30

Lock
released,
session created
Released inside the
session
Displayed on opening
Refused without it
No session, cabinet
stayed shut
Cabinet stayed shut
Written to the trail
Works; not timed over
trials
Works; not timed over
trials
Needs a controlled trial
set
Needs a controlled trial
set
No real SIM card

We found one fault, and we report it instead of quietly fixing it,
because it shows why testing with real data matters. The server sent all 39
records, but the website showed none of them. The reason: the server had
learned two new kinds of record that the website did not know about. The
website checks the whole list at once, so one unknown item threw away all
39. The spreadsheet page, which checks each row on its own, showed
everything. That difference is what told us where the fault was. The saved
records themselves were never harmed.
3.4 System Requirements
Table 7 states the requirements the system was designed against,
separated into what it must do and how it must behave. These are the
statements the tests above were written to check.

31

Table 7
What the system must do
No.

Requirement

What it must do
F1
The door opens only for a finger signed up on the door
sensor.
F2
A door scan starts a session for that one person, which
ends by itself.
F3
The cabinet opens only for the person holding a
running session.
F4
Every decision is saved with the person, the reader,
and the time.
F5
The cabinet shows a one-time code, and no borrow
record is accepted without it.
F6
The website shows which readers are working.
How it must behave
N1
Readers never decide on their own.
N2
Fingerprints never leave the sensor.
N3
Nobody can edit or delete a saved reader record, not
even an administrator.
N4
Each reader has its own password, which can be
changed on its own.
N5
The program must fit in the chip with room to spare.
N6
The reader must never freeze while the lock is open or
a message is showing.

Every requirement in the table was exercised during testing. F1 to
F6 were demonstrated on the assembled readers, as recorded in Table 6.
N1, N2 and N4 follow from how the system is built and were confirmed by
inspection: a reader holds no decision logic, no template leaves the sensor,
and each reader carries its own credentials. N3 was confirmed by attempting
to edit a reader record through the interface, which offers no route to do so.
N5 is measured below. N6 was observed on the hardware, where a second
finger could be presented while a message was still on screen.
32

3.5 Performance Analysis
Performance is examined here in two ways. The first is what the
finished program demands of the chip, which the build reports exactly. The
second is how the design sits against systems that have already been
measured and published.
3.5.1 Use of Chip Resources
Our program fills about 81 percent of its 1.2 MB space. That meets
requirement N5, but only just. Adding features later will be limited by this,
not by speed or memory.
RAM is not a problem, and the reason is a design choice. Fingerprints
stay in the sensor, so the biggest piece of data never reaches our chip. That
turns the usual tightest limit on this kind of project into a non-issue. It also
answers the small-memory warning raised by Rahman et al. (2026).
Speed is not a problem either. Espressif Systems (2025) rate the chip
at 1079.96 CoreMark, a standard speed score. Our reader only waits on a
slow sensor, builds a short message, and keeps Wi-Fi alive. Two processors
mean the Wi-Fi keeps running while the sensor is read.
3.5.2 Timing
Table 8 separates the intervals fixed by the design, which are known
exactly, from those that depend on the sensor and the network and would
have to be timed over repeated trials.

33

Table 8
Timings we set, and timings still to be measured

Interval

Value

Status

Session length

120 s

Set in the server

Code lifetime

300 s

Set in the server

Lock stays open

3s

Set in the reader

Message on screen

2.5 s

Set in the reader

“Still here” signal

30 s

Set in the reader

Scan time

[MEASURE]

Observed to work; not
timed

Unlock time

[MEASURE]

Observed to work; not
timed

3.5.3 Comparison With Published Systems
The figures below belong to other people’s systems. They are the
benchmarks this system should be compared against once its own numbers
are recorded.
Alsayaydeh et al. (2025) measured a scan at about one second and
an unlock at five seconds on a setup much like ours. They admitted the
wrong person 1.32 percent of the time and turned away the right person
26.32 percent of the time. The second figure is the warning. A system that
rejects one honest person in four will end up propped open, and a propped
door defeats everything behind it.
Mohammed et al. (2025) report a mean authentication time of 235
milliseconds and a 68 percent drop in fraudulent access. Their timing is not
34

a fair comparison, since their pipeline runs on server-class machines rather
than a microcontroller. The 68 percent is the relevant figure: it is the scale
of improvement that checking twice is expected to deliver, and the effect the
door-to-cabinet sequence is built to reproduce.
Two properties of this system have no counterpart in either study.
Refusals are recorded as carefully as approvals, so tailgating attempts
become a countable quantity rather than an assumption, and the refusal
tests above confirm those records are written. Reader events are also
append-only by construction, which is the accountability property Koisser
and Sadeghi (2023) argue a record must have before it can be used as
evidence.

35

CHAPTER 4: CONCLUSION
4.1 Problems Encountered
Six problems shaped the final design. The first three appeared in
the software, where they were found and corrected. The next two were
electrical, and were caught while the readers were being assembled. The
last belongs to the room itself.
4.1.1 Slot Numbers Meant Different People
Each sensor keeps its own list of fingerprints. Slot 7 on the door
sensor and slot 7 on the cabinet sensor are two different people. Our first
design treated slot 7 as one person everywhere. That would have opened
the cabinet for the wrong person, and the record would have looked perfectly
normal.
4.1.2 A Reader Cannot Be Trusted to Decide
At first each reader decided by itself and then told the server. That
is easy to build and wrong. A reader hangs on a wall. Anyone can open it
and copy or fake its messages. Anything that decides who gets in has to be
decided by the server.
4.1.3 One Unknown Record Emptied the Whole Page
Described in Chapter 3. The server learned two new kinds of record.
The website did not know them, so it threw away all 39 records instead of
just the two. The page looked empty, and no error was shown.
4.1.4 Settings Were Cut Without Warning
The server reads its settings from a text file. That file quietly cuts
anything after a space. A name with a space in it gets shortened, and nothing
tells you.
36

4.1.5 Electrical Problems That Only Appear in Hardware
Three problems surfaced while the readers were being wired up. The
lock pulls a lot of current when it opens and will restart the chip if the two
share one supply. The text unit does the same when it sends. And one of
its wires cannot take the chip’s full signal strength. Each of these shows up
as a random restart, which is hard to trace back to its cause.
4.1.6 The Door Reader May Not Reach the Wi-Fi
The door is the farthest point from the router. A reader that cannot
reach the server cannot ask permission, and by design it will not decide
alone. So it opens nothing.
4.2 Troubleshooting
This section describes how the problems above were traced. In each
case the useful part was not the fix but the observation that made the fault
visible in the first place.
4.2.1 Finding the Empty Page Fault
The server replied correctly with a full page of data, so the server and
the network were ruled out at once. The clue was that the spreadsheet page
showed all 39 records while the record page showed none. Both read the
same data, so the difference had to be in how each one read it. Comparing
the kinds of record in the data against the kinds the website accepted found
the two unknown ones.
The wider lesson is what made it visible at all: we tested with real
data. With an empty database both pages show nothing, and the fault would
have looked like normal behaviour.

37

4.2.2 Always Start With Something That Works
Every round of testing began with a request we knew should succeed.
Without that, a test where everything fails only proves the server is off. It says
nothing about the parts being tested.
4.2.3 Checking Code Before Flashing
Before the boards were flashed, the only available checks were the
ones the tools can make: that the code compiles, that the modules link, and
that the image fits the chip with measurable room left. Those checks caught
real mistakes early, but they cannot show behaviour. Everything about how
the system actually behaves came afterwards, from the assembled readers.
4.3 Solutions and Conclusions
This section sets out what was changed in response to those
problems, what the study achieved, and what it was not able to show.
4.3.1 What We Fixed
Finger records now carry the name of the reader they came from, so
a slot number can never be matched against the wrong sensor. The cost is
that people sign up twice, once at each reader. We accepted that cost rather
than hide it.
All decisions moved to the server. Readers log in with their own ID
and password, not a person’s, so a stolen reader gives away only itself.
Reader records were made permanent, with no way to edit or delete them
for anyone, including administrators. A wrong record is corrected by adding
a right one.
The electrical problems were solved in the wiring. The lock and the
text unit each got their own power supply, sharing only a ground wire with

38

the chip, and the text unit’s weak wire got a voltage reducer. Where the door
reader cannot reach the Wi-Fi, the cabinet reader can share its connection.
The empty page fault is still open. The fix is to teach the website all
the kinds of record the server sends, and to check each row on its own so
one unknown item cannot throw away a whole page.
4.3.2 Conclusion
This project set out to prove who took materials from a school
stockroom, and to record it so nobody can change it afterwards.
The design goals were met.

We documented how the chip’s

processors, memory, pins, and Wi-Fi work, and showed that each one
shaped a real decision. The clearest example is memory. By leaving
fingerprints in the sensor, the largest piece of data never reaches the chip.
What is usually the tightest limit on this kind of project stopped being a limit
at all.
The software goals were met and tested. The two-step check, the
session, the permanent record, and the code-locked borrow list all work, and
Chapter 3 shows the results. Safety comes from the shape of the design,
not from one clever part. Decisions sit in one place, readers can only speak
as themselves, and refusals are saved as carefully as approvals.
The main goal was demonstrated. Both readers were built, flashed,
and run through the full sequence. The cabinet refused a finger that held no
door session, and the attempt was written to the record. What remains is
measurement rather than function. Until scan time, unlock time, and error
rates are recorded over repeated trials, this system cannot be set beside the
figures reported by Alsayaydeh et al. (2025), and the 68 percent reduction
that Mohammed et al. (2025) measured cannot be confirmed in this setting.
39

Two limits remain even now that the hardware is built. The sensor
does the matching, so we inherit its accuracy and have no way to spot a
fake finger; the seaweed-jelly fakes shown by Rad et al. (2024) would get
through. And the borrow list is still typed by a person. We can prove the
cabinet opened and who opened it, but not that the typed list is complete.
Closing that gap would mean sensing the items themselves, which is a
different project.
4.3.3 Recommendations
The following work would close the gaps this study leaves open. The
first item matters most, because it is the difference between a system shown
to work and a system whose performance is known.
1. Record scan time, unlock time, and error rates over a controlled set of
trials, so the system can be compared against published figures.
2. Fix the empty page fault before the system is used for real.
3. Test with a real SIM card and a real phone network.
4. Consider a sensor with fake-finger detection, given the weakness
shown by Rad et al. (2024).
5. Watch the refusal count once the system runs. It shows how often
tailgating is actually tried.

40

References
Alrawili, R., AlQahtani, A. A. S., & Khan, M. K. (2024). Comprehensive
survey: Biometric user authentication application, evaluation, and
discussion. Computers and Electrical Engineering, 119, 109485.
https://doi.org/10.1016/j.compeleceng.2024.109485
Alsayaydeh,

J. A.

J., Yusof,

M.

F.,

Mamchenko,

S.,

Hamzah,

R. A., & Herawan, S. G. (2025). Design and evaluation
of a biometric IoT-based smart lock system with real-time
monitoring
of

and

Advanced

alert

mechanisms.

Computer

Science

and

International
Applications,

Journal
16(7).

https://doi.org/10.14569/IJACSA.2025.0160737
Cepeda, J. A. U., & Saludes, A. J. C. (2025). Online ICT equipment inventory
and borrowing system with decision support. European Journal of
Innovative Studies and Sustainability, 1(5), 62–70. https : / / doi . org /
10.59324/ejiss.2025.1(5).07
Espressif Systems. (2025). ESP32 series datasheet (Version 5.3). https :
/ / www . espressif . com / sites / default / files / documentation / esp32 _
datasheet_en.pdf
Koisser, D., & Sadeghi, A.-R. (2023). Accountability of things: Large-scale
tamper-evident logging for smart devices. arXiv: 2308 . 05557
[cs.CR]. https://arxiv.org/abs/2308.05557
Linuwih, H. W., & Handayati, Y. (2025). Quantitative analysis of inventory
record inaccuracy (IRI): A case study on warehouse stock
discrepancies. International Journal of Current Science Research
and Review, 8(1). https://doi.org/10.47191/IJCSRR/V8-I1-26

41

Mohammed, A., Salama, A., Shebka, N., & Ismail, A. (2025). Enhancing
network access control using multi-modal biometric authentication
framework. Engineering, Technology & Applied Science Research,
15(1), 20144–20150. https://doi.org/10.48084/etasr.9554
OWASP

Foundation.

(2026).

Session

management

cheat

sheet

[Continuously maintained; last revised August 2026]. Retrieved
September 11, 2026, from https : / / cheatsheetseries . owasp . org /
cheatsheets/Session_Management_Cheat_Sheet.html
Rad, P., Dorai, G., & Jozani, M. (2024). From seaweed to security: The
emergence of alginate in compromising IoT fingerprint sensors. arXiv:
2404.02150 [cs.CR]. https://arxiv.org/abs/2404.02150
Rahman, M. H., Shihab, M., Rahman, M. A., & Naderuzzaman,
M. (2026). ESP32 microcontroller: A review of architecture,
communication protocols, applications and research challenges.
Open Access Journal on Engineering Applications, 1(2), 19–33.
https://doi.org/10.64886/oajea.0102.003

42

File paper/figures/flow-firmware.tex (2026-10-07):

\begin{tikzpicture}[flow, x=1mm, y=0.93mm,
  proc/.append style={text width=24mm, minimum width=26mm},
  io/.append style={text width=19mm},
  end/.style = {term, minimum width=14mm}]

\node[term] (on)   at (0,0)    {Start};
\node[proc] (su1)  at (0,-12)  {Start serial, screen\\and lock};
\node[dec]  (sen)  at (0,-27)  {Sensor\\found?};
\node[deny] (hlt)  at (34,-27) {Show error\\and halt};
\node[end]  (x1)   at (62,-27) {Stop};
\node[proc] (su2)  at (0,-43)  {Join Wi-Fi, set clock,\\start SIM800L};
\node[proc] (mem)  at (0,-57)  {Check free memory};
\node[dec]  (door) at (0,-72)  {Door switch\\changed?};
\node[proc] (buzz) at (34,-72) {Warn at 30~s,\\alarm at 60~s};
\node[dec]  (btn)  at (0,-90)  {Enroll button\\pressed?};
\node[proc] (enr)  at (34,-90) {Run one\\enrollment step};
\node[io]   (poll) at (0,-106) {Poll sensor\\on UART2};
\node[dec]  (fp)   at (0,-121) {Finger\\matched?};
\node[io]   (scan) at (34,-121) {Send\\cabinet:slot};
\node[dec]  (ok)   at (68,-121) {Reply is\\unlock?};
\node[proc] (open) at (102,-137) {Release lock 4~s,\\show code 15~s};
\node[deny] (why)  at (68,-137) {Show the reason,\\stay locked};
\node[dec]  (hb)   at (0,-155) {30~s since\\heartbeat?};
\node[io]   (hbs)  at (34,-155) {Send\\heartbeat};
\node[dec]  (sms)  at (0,-173) {15~s since\\SMS check?};
\node[io]   (smss) at (34,-173) {Send up to 3\\queued texts};
\node[proc] (wait) at (0,-190) {Wait 50 ms};

\draw[arr] (on.south) -- (su1.north);
\draw[arr] (su1.south) -- (sen.north);
\draw[arr] (sen.east) -- node[lbl, above] {no} (hlt.west);
\draw[arr] (hlt.east) -- (x1.west);
\draw[arr] (sen.south) -- node[lbl, left, pos=0.3] {yes} (su2.north);
\draw[arr] (su2.south) -- (mem.north);
\draw[arr] (mem.south) -- (door.north);
\draw[arr] (door.east) -- node[lbl, above] {yes} (buzz.west);
\draw[arr] (door.south) -- node[lbl, left, pos=0.15] {no} (btn.north);
\draw[arr] (buzz.south) |- (0,-81);
\draw[arr] (btn.east) -- node[lbl, above] {yes} (enr.west);
\draw[arr] (enr.east) -- (52,-90) |- (mem.east);
\draw[arr] (btn.south) -- node[lbl, left, pos=0.3] {no} (poll.north);
\draw[arr] (poll.south) -- (fp.north);
\draw[arr] (fp.east) -- node[lbl, above] {yes} (scan.west);
\draw[arr] (scan.east) -- (ok.west);
\draw[arr] (ok.east) -| node[lbl, above, pos=0.25] {yes} (open.north);
\draw[arr] (ok.south) -- node[lbl, right] {no} (why.north);
\draw[arr] (open.south) |- (0,-146);
\draw (why.south) -- (68,-146);
\draw[arr] (fp.south) -- node[lbl, left, pos=0.1] {no} (hb.north);
\draw[arr] (hb.east) -- node[lbl, above] {yes} (hbs.west);
\draw[arr] (hbs.south) |- (0,-164);
\draw[arr] (hb.south) -- node[lbl, left, pos=0.15] {no} (sms.north);
\draw[arr] (sms.east) -- node[lbl, above] {yes} (smss.west);
\draw[arr] (smss.south) |- (0,-182);
\draw[arr] (sms.south) -- node[lbl, left, pos=0.15] {no} (wait.north);
\draw[arr] (wait.west) -- (-20,-190) |- node[lbl, left, pos=0.25, rotate=90, anchor=south] {repeat forever} (mem.west);

\end{tikzpicture}

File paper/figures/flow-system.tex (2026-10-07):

\begin{tikzpicture}[flow, x=1mm, y=1mm,
  side/.style = {deny, text width=16mm, minimum width=18mm},
  end/.style = {term, minimum width=14mm}]

\draw[gray!55, dashed, rounded corners=3pt] (-19,8) rectangle (19,-172);
\draw[gray!55, dashed, rounded corners=3pt] (23,8) rectangle (84,-172);
\draw[gray!55, dashed, rounded corners=3pt] (87,8) rectangle (119,-172);
\node[lanetitle] at (0,9)    {ESP32 readers};
\node[lanetitle] at (53.5,9) {Backend server};
\node[lanetitle] at (103,9)  {Frontend website};

\node[term] (s1) at (0,0)    {Start};
\node[io]   (e1) at (0,-15)  {Read finger, send\\door:slot};
\node[proc] (b1) at (40,-15) {Check reader\\ID and secret};
\node[dec]  (b2) at (40,-32) {Reader and\\finger valid?};
\node[side] (r1) at (70,-32) {Refuse,\\reply deny};
\node[end]  (x1) at (70,-44) {Stop};
\node[proc] (b3) at (40,-54) {Open 120~s session,\\save door grant};
\node[proc] (e2) at (0,-54)  {Show Welcome,\\release door};
\node[io]   (f1) at (103,-54) {Live feed on\\dashboard};

\node[proc] (s2) at (0,-69)  {Walk to\\the cabinet};
\node[io]   (e3) at (0,-84)  {Read finger, send\\cabinet:slot};
\node[dec]  (b4) at (40,-84) {Live session\\for this user?};
\node[side] (r2) at (70,-84) {Save refusal,\\reply deny};
\node[end]  (x2) at (70,-97) {Stop};
\node[proc] (b5) at (40,-104) {Issue one-time code,\\save cabinet grant,\\queue SMS};
\node[proc] (e4) at (0,-104) {Release lock 4~s,\\show the code};

\node[io]   (f2) at (103,-120) {Type code and\\borrowed items};
\node[dec]  (b6) at (40,-136) {Code valid\\for this user?};
\node[side] (r3) at (70,-136) {Log rejected\\code, show error};
\node[end]  (x3) at (70,-149) {Stop};
\node[proc] (b7) at (40,-156) {Save checkout,\\mark code spent};
\node[proc] (f3) at (103,-156) {Checkout\\on record};
\node[end]  (x4) at (103,-167) {Stop};

\draw[arr] (s1.south) -- (e1.north);
\draw[arr] (e1.east) -- (b1.west);
\draw[arr] (b1.south) -- (b2.north);
\draw[arr] (b2.east) -- node[lbl, above] {no} (r1.west);
\draw[arr] (r1.south) -- (x1.north);
\draw[arr] (b2.south) -- node[lbl, right] {yes} (b3.north);
\draw[arr] (b3.west) -- node[lbl, above] {unlock} (e2.east);
\draw[dashedarr] (b3.east) -- (f1.west);
\draw[arr] (e2.south) -- (s2.north);
\draw[arr] (s2.south) -- (e3.north);
\draw[arr] (e3.east) -- (b4.west);
\draw[arr] (b4.east) -- node[lbl, above] {no} (r2.west);
\draw[arr] (r2.south) -- (x2.north);
\draw[arr] (b4.south) -- node[lbl, right] {yes} (b5.north);
\draw[arr] (b5.west) -- node[lbl, above] {code} (e4.east);
\draw[dashedarr] (b5.east) -| (f1.south);
\draw[dashedarr] (e4.south) |- node[lbl, above, pos=0.75] {person reads the code} (f2.west);
\draw[arr] (f2.south) |- ($(b6.north)+(0,5)$) -- (b6.north);
\draw[arr] (b6.east) -- node[lbl, above] {no} (r3.west);
\draw[arr] (r3.south) -- (x3.north);
\draw[arr] (b6.south) -- node[lbl, right] {yes} (b7.north);
\draw[arr] (b7.east) -- (f3.west);
\draw[arr] (f3.south) -- (x4.north);

\end{tikzpicture}

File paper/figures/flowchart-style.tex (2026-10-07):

\definecolor{termFill}{HTML}{E8F5E9}
\definecolor{termStroke}{HTML}{43A047}
\definecolor{procFill}{HTML}{E1F5FE}
\definecolor{procStroke}{HTML}{0277BD}
\definecolor{decFill}{HTML}{FFF9C4}
\definecolor{decStroke}{HTML}{F9A825}
\definecolor{ioFill}{HTML}{FFF3E0}
\definecolor{ioStroke}{HTML}{EF6C00}
\definecolor{stopFill}{HTML}{FCE4EC}
\definecolor{stopStroke}{HTML}{C2185B}

\tikzset{
  flow/.style = {
    font=\sffamily\scriptsize,
    every node/.append style={execute at begin node=\linespread{1}\selectfont},
    >=Stealth,
  },
  term/.style = {
    rounded rectangle, draw=termStroke, thick, fill=termFill,
    minimum width=22mm, minimum height=7mm, align=center, inner sep=2pt,
  },
  proc/.style = {
    rectangle, rounded corners=2pt, draw=procStroke, thick, fill=procFill,
    minimum width=28mm, minimum height=7mm, text width=26mm, align=center,
    inner sep=2pt,
  },
  io/.style = {
    trapezium, trapezium left angle=70, trapezium right angle=110,
    trapezium stretches body, draw=ioStroke, thick, fill=ioFill,
    minimum width=26mm, minimum height=7mm, text width=21mm, align=center,
    inner sep=2pt,
  },
  dec/.style = {
    diamond, aspect=2, draw=decStroke, thick, fill=decFill,
    align=center, inner sep=0pt, text width=17mm,
  },
  deny/.style = {
    proc, draw=stopStroke, fill=stopFill,
  },
  lanetitle/.style = {
    font=\sffamily\footnotesize\bfseries, anchor=south,
  },
  arr/.style = {->, thick, draw=gray!70!black},
  dashedarr/.style = {arr, dashed},
  lbl/.style = {font=\sffamily\tiny, text=black!80, inner sep=2.5pt},
}

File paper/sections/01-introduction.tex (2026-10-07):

\chapterhead{Introduction}

\sectionhead{Background of the Study}

Schools lend laboratory equipment to their students and staff, and keeping track
of what has gone out is a recognised management problem
\parencite{cepeda2025}. \textcite{cepeda2025} examined equipment lending at a
Philippine university and reported that handling the process by hand left the
institution weak in three areas at once: operational efficiency, data accuracy,
and accountability. Those three weaknesses are the reason such institutions move
to recorded, automated lending \parencite{cepeda2025}. The gap survives because
entry to a room and the record of what left it are governed by two separate
mechanisms that never verify one another \parencite{cepeda2025}.

Records maintained by hand also drift away from the physical stock they are
meant to describe \parencite{linuwih2025}. \textcite{linuwih2025} counted stock
against the written record in a warehouse and found that 52.85 percent of
product types did not match during a single stocktake. A written record that
disagrees with the shelf in more than half of cases cannot settle a question
about who holds what \parencite{linuwih2025}. Physical keys carry a separate
weakness of their own \parencite{alrawili2024}. \textcite{alrawili2024} observe
that anything a person carries, as opposed to something a person is, can be
handed to somebody else. A key is therefore able to be lent, copied, or lost,
after which the lock records only that somebody held a key rather than who that
person was \parencite{alrawili2024}.

Biometric identification answers that weakness directly, because a fingerprint
belongs to the person rather than being carried by them
\parencite{alrawili2024}. \textcite{alrawili2024} reviewed how such systems are
chosen and found that the choice is always a balance. A system has to be
secure, but it also has to be convenient and robust, or it will not survive
contact with the people who use it \parencite{alrawili2024}. Fingerprints sit at
a workable point on that balance, being inexpensive to read and quick enough to
complete a scan in roughly one second on low-cost hardware
\parencite{alsayaydeh2025}.

Fingerprint locks built on low-cost microcontrollers are now a well documented
application of this hardware \parencite{rahman2026}.
\textcite{alsayaydeh2025} built one using an ESP32, a small computer chip with
built-in Wi-Fi. Their lock read a finger in roughly one second and released the
door about five seconds later \parencite{alsayaydeh2025}. It admitted the wrong
person 1.32 percent of the time, which is a good result
\parencite{alsayaydeh2025}. It also turned away the right person 26.32 percent
of the time, so nearly one legitimate user in four had to present a finger again
\parencite{alsayaydeh2025}. That rejection figure is the convenience side of the
balance described by \textcite{alrawili2024}, on which a system that is not
convenient will not survive contact with its users.

A single reader also carries a limit that no improvement in sensor accuracy can
remove, since one reader verifies only the credential presented to it and
nothing about the person who may have entered alongside its user
\parencite{mohammed2025}. Researchers have answered this by verifying a person
more than once rather than by trying to perfect a single check
\parencite{mohammed2025}.
\textcite{mohammed2025} tested a system built this way
and measured a 68 percent drop in fraudulent access. The gain came from
requiring more than one independent confirmation before granting entry, not from
a more accurate sensor \parencite{mohammed2025}. Their framework still answered
in 235 milliseconds on average, so the extra check did not make the system slow
\parencite{mohammed2025}.

The record itself must also resist alteration, since a saved list is only
useful if nobody can revise it after an incident \parencite{koisser2023}.
\textcite{koisser2023} studied this problem across connected devices and
describe tampering as the central weakness of digital records, which is why
their scheme is built to make any modification detectable rather than merely
discouraged. Read together, these findings describe one design: verify a person
twice and bind the second check to the first \parencite{mohammed2025}, then hold
the result where it cannot be edited \parencite{koisser2023}.

\sectionhead{Statement of the Problem}

A school stockroom cannot prove who took its materials, because the
accountability its records are meant to provide is precisely what manual
handling fails to deliver \parencite{cepeda2025}. Two weaknesses produce this
failure. A single reader verifies only the credential presented to it, so a
person admitted alongside an authorized user is never evaluated and never
recorded, which is the weakness \textcite{mohammed2025} address by requiring
more than one confirmation. Written records then disagree with the physical
stock they describe in more than half of the product types examined
\parencite{linuwih2025}, and moving those records onto a computer does not
repair the problem, since a list that can still be revised afterwards carries
the same weakness as a paper one \parencite{koisser2023}. The institution is
therefore left unable to show either that its list of names is complete or that
nothing on it was altered later, which are the two properties an accountable
record requires \parencite{koisser2023, linuwih2025}.

Existing work addresses the parts of this problem separately, and the gap
lies between them \parencite{alsayaydeh2025, mohammed2025, koisser2023,
cepeda2025}. Fingerprint locks on low-cost microcontrollers guard a single
control point \parencite{alsayaydeh2025}. Requiring more than one confirmation
is known to cut fraudulent access, but that result was obtained by combining
modalities at one point on server-class hardware rather than by sequencing them
across two physical locations \parencite{mohammed2025}. Tamper-evident logging
is well developed, and recent work brings it within reach of resource-limited
devices \parencite{yagiz2026}, yet it is treated as a logging problem rather
than one bound to a physical access decision \parencite{koisser2023}. Per-device
credentials and replay resistance have likewise been demonstrated on ESP32-class
hardware in isolation \parencite{lkhluf2026}. Equipment borrowing has been moved
onto computers, but the written claim is not tied to a physical opening
\parencite{cepeda2025}, which is why records still drift from the shelf
\parencite{linuwih2025}. Across the work reviewed here
\parencite{alsayaydeh2025, mohammed2025, koisser2023, yagiz2026,
lkhluf2026, cepeda2025, linuwih2025}, no single reported system joins these
into one scheme: sequential, identity-bound verification across two control
points, running on low-cost microcontrollers, with an unalterable record
that binds what was taken to the opening that allowed it.

Specifically, this study seeks to answer the following questions:

\begin{enumerate}
  \item Can sequential, identity-bound verification across two control points be
        implemented on low-cost microcontrollers, given that the reduction in
        fraudulent access reported by \textcite{mohammed2025} was obtained on
        server-class hardware?
  \item What session lifetime binds the second check to the first without
        obstructing legitimate use, given the rejection rate reported for
        single-reader fingerprint locks \parencite{alsayaydeh2025} and the
        idle-timeout range recommended for high-value applications
        \parencite{owasp2026}?
  \item Can an access record be held unalterable by every role, including
        administrators, on a system of this scale, where tamper-evident logging
        has so far been treated separately from the access decision itself
        \parencite{koisser2023, yagiz2026}?
  \item Can a written record of borrowed items be bound to a physical opening,
        closing the gap left when borrowing is digitised without such a link
        \parencite{cepeda2025, linuwih2025}?
  \item Do the processor, memory, input/output, and communication resources of
        the ESP32 support this combination, given the limited on-chip memory
        identified as the platform's standing constraint \parencite{rahman2026}?
  \item What residual weaknesses remain in a design that delegates matching to
        the sensor, given that low-cost fingerprint modules have been shown to
        be spoofable \parencite{rad2024}?
\end{enumerate}

\sectionhead{Objectives of the Study}

The general objective of this study is to design and build an embedded system
that can prove who took materials from a school stockroom, and can store that
proof in a form that nobody is able to change afterwards.

The specific objectives below answer the six questions above, in the same
order, each stating what the study builds or measures to settle its
matching question.

\begin{enumerate}
  \item To implement sequential, identity-bound verification on two low-cost
        microcontroller readers, so that the cabinet opens only for the person
        the door admitted, and to demonstrate it on assembled hardware rather
        than on server-class equipment \parencite{mohammed2025}.
  \item To set and enforce a door session lifetime of 120 seconds, taken from
        the 2 to 5 minute idle timeout recommended for high-value applications
        \parencite{owasp2026}, and to close it automatically.
  \item To hold every scan, whether allowed or refused, in a record that offers
        no route to edit or delete it for any role, administrators included
        \parencite{koisser2023}.
  \item To bind a written list of borrowed items to a physical opening by
        requiring a one-time code that only the opening cabinet displays
        \parencite{cepeda2025}.
  \item To document how the processor, memory, input/output, and communication
        resources of the ESP32 support this combination, and to measure what the
        finished program costs against the limited on-chip memory that
        \textcite{rahman2026} identify as the platform's standing constraint.
  \item To state the residual weaknesses of the design, including those
        inherited by delegating fingerprint matching to a sensor module of a
        class shown to be spoofable \parencite{rad2024}.
\end{enumerate}

\sectionhead{Significance of the Study}

This study is useful to the groups described below.

\textbf{Students.} Students who borrow equipment gain a fair and complete
record. Because every scan is saved with a name and a time, a student cannot
easily be blamed for something that somebody else removed. The record protects
the borrower just as much as it protects the school, and it removes the argument
that so often follows a missing item. Students also gain a faster way of
borrowing, since there is no notebook to find and no queue behind the person
writing in it.

\textbf{Teachers and laboratory staff.} Staff no longer need to read other
people's handwriting or chase students for entries that were never made. The
list builds itself as people use the room, and it can be searched in seconds
rather than flipped through page by page. Staff can also see at a glance whether
a reader has stopped working, instead of discovering it only when something goes
wrong.

\textbf{Stockroom custodians and administrators.} Administrators gain something
a notebook can never provide, which is proof. When an item goes missing they can
see exactly who opened the cabinet, at what time, and what was logged against
that opening. This speaks directly to the record inaccuracy measured by
\textcite{linuwih2025}, where more than half of the product types checked
disagreed with their written record. Administrators can also see refused
attempts, which reveals whether people are trying to enter when they should not
be. That second view turns a vague worry about losses into a number that can be
watched over time.

\textbf{The school.} Laboratory equipment is expensive and school budgets are
limited. Better records mean fewer unexplained losses, and they support better
decisions about what needs replacing and how much to buy. Over several terms,
the record also shows which items are used heavily and which sit untouched.

\textbf{Future researchers.} This study documents what worked and what did not,
including a fault discovered during testing and the measurements still to be
taken. Other students can reuse the design, extend it to more rooms, or take the
honest account of its limits as a starting point and avoid repeating the same
mistakes.

\sectionhead{Scope and Limitations}

This study covers one door and one storage cabinet inside a single school
stockroom, served by two reader units and one server. A server is the computer
that stores all the records and makes the decisions about who may enter. The
system handles signing up a fingerprint, the two scans, the borrowing record,
the saved history, and text message alerts. It also shows different information
to students, teachers, and administrators, so that a student sees only their own
records while an administrator sees everything.

The study carries the following limits, and every claim made later in this paper
should be read against them.

\begin{enumerate}
  \item \textbf{Performance was not measured in numbers.} Both readers were
        built, wired, flashed and exercised through the complete door-to-cabinet
        sequence, so the system is demonstrated to work. What the study does not
        provide is quantitative performance data: scan time, unlock time and
        error rates were not recorded over a controlled set of trials, so no
        such figure is claimed here.
  \item \textbf{The sensor does the matching.} Fingerprints are stored and
        compared inside the sensor itself, never on our chip. The system is
        therefore only as accurate as the sensor, and it has no way of telling a
        real finger from a fake one. \textcite{rad2024} showed that copies made
        from seaweed jelly can fool this kind of sensor.
  \item \textbf{People must sign up twice.} Once at the door and once at the
        cabinet, because each sensor keeps its own separate list of fingers.
  \item \textbf{The borrowed list is still typed by a person.} The system can
        prove that the cabinet opened and who opened it. It cannot check whether
        the list of items typed afterwards is complete or honest.
  \item \textbf{Text messages were not sent over a real network.} They were
        tested using a stand-in program on the computer rather than a real SIM
        card and a real phone line.
  \item \textbf{One room only.} The design was not tested across several rooms
        or with several cabinets running at the same time.
\end{enumerate}

\sectionhead{Definition of Terms}

The terms below are listed in alphabetical order and are defined as they are
used in this study.

\begin{description}
  \item[Audit trail] The saved list of every scan and every decision the system
        has made.
  \item[Embedded system] A small computer built into a device to do one
        particular job.
  \item[ESP32] The chip used in this project. It is a small computer with
        built-in Wi-Fi.
  \item[Fingerprint sensor] The part that reads a finger and compares it against
        a list stored inside itself.
  \item[Memory] Space inside the chip that holds the program and the data it is
        working on.
  \item[Relay] An electric switch that lets a small chip control a much stronger
        power supply.
  \item[Server] The main computer that keeps every record and decides who may
        enter.
  \item[Session] A short time window, 120 seconds in this study, that opens when
        somebody scans at the door.
  \item[Solenoid lock] An electric lock that opens while power is sent to it and
        locks again when the power stops.
  \item[Tailgating] Walking into a room behind somebody who has just opened the
        door, without scanning a finger.
\end{description}

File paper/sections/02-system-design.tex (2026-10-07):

\chapterhead{System Design}

\sectionhead{System Overview}

The system has three parts: a reader at the door, a reader at the cabinet, and
one server. Each reader is an ESP32 chip with a fingerprint sensor, a small
screen, and an electric lock.

The readers never decide anything by themselves. When someone scans a finger,
the sensor finds a match and gives back a slot number. The reader sends that
number to the server. The server decides, saves the result, and sends back a
yes or no.

This matters because a reader hangs on a wall where anyone can reach it. If a
reader could decide on its own, someone could open it and fool it. The server
sits in a locked place, so the decision stays safe.

Access happens in two steps. A finger at the door unlocks the door and starts a
120-second session for that one person. A finger at the cabinet opens it only if
it belongs to the same person, and only while the session is still running. A
registered finger with no session is refused, and the refusal is saved. This is
the double check that \textcite{mohammed2025} found cuts fake entries.

The 120-second figure is not arbitrary. \textcite{owasp2026} recommend an idle
timeout of 2 to 5 minutes for high-value applications, against 15 to 30 minutes
for low-risk ones, and a stockroom of shared equipment belongs in the first
group. We took the strictest end of that range. Two minutes is long enough to
cross a room and reach the cabinet, and short enough that a person who walks
away leaves nothing useful behind them.

When the cabinet opens, it shows a one-time code on its screen. The website will
not accept a borrow record without that code. So every written record matches a
real opening. Reader records can never be edited or deleted. This is the
protection \textcite{koisser2023} say a log needs.

\sectionhead{System Architecture}

The architecture is described at five levels. The first covers how the separate parts connect to one another. The four that follow look inside a single reader, at its processor, its memory, the pins it uses to reach the outside world, and the network it speaks over.

\subsectionhead{Overall System Architecture}

The system is three programs working together. The ESP32 firmware runs on the
two readers and handles the sensor, the screen, and the lock. The backend is a
server written in Rust that holds the database and makes every decision. The
frontend is a website, built with SvelteKit, where people sign in, enter what
they borrowed, and read the record. The readers talk only to the backend, never
to each other and never to the website.

Figure~\ref{fig:overall} follows one complete use through all three, with one
lane for each program. Solid arrows are requests and replies. Dashed arrows are
things that happen without anybody asking: the live feed updating on the
dashboard, and the person carrying the code from the cabinet screen to the
website. Every decision diamond sits in the backend lane, because the readers
only report what they read and act on the answer.

\begin{figure}[H]
\centering
\caption{One complete use, followed through the readers, the backend, and the
frontend}
\label{fig:overall}
\input{figures/flow-system}
\end{figure}

If the door reader is out of Wi-Fi range, the cabinet reader can share its own
connection with it. This bridge is built into the cabinet firmware but is
switched off by default, since it is only needed where the door is too far from
the router.

\subsectionhead{Microcontroller Architecture}

Both readers use the ESP32. The chip carries two processors, each able to run at
up to 240 MHz, and is rated at 1079.96 CoreMark in that configuration
\parencite{espressif2025}. \textcite{rahman2026} reviewed the platform and
identified the combination of dual-core processing, integrated radios and
peripheral support as its principal strength, while naming limited on-chip
memory and real-time constraints as its standing weaknesses.

The second processor is what makes the workload here practical. The fingerprint
sensor is slow relative to the processor, so one core can wait on the sensor
while the other holds the network connection open.

\subsectionhead{Memory Architecture}

The chip provides 448 KB of ROM for start-up code, 520 KB of on-chip RAM for
running programs, and two smaller low-power regions of 8 KB each, with the
application image held in external flash and executed through a cache
\parencite{espressif2025}. Limited on-chip memory is the constraint
\textcite{rahman2026} single out as the platform's most persistent difficulty.

Table~\ref{tab:memory} shows how this project uses those regions. Our program
fills about 81 percent of the 1.2 MB partition set aside for it, which leaves
room to grow but not a great deal of it.

One design choice removes the memory pressure that \textcite{rahman2026}
describe. Fingerprints are never stored on our chip; they stay inside the
sensor, which returns only a slot number. Fingerprint data is the largest
structure the reader would otherwise hold, so leaving it on the sensor keeps the
520 KB of RAM \parencite{espressif2025} comfortable rather than tight.

\begin{table}[H]
\centering
\caption{How the chip uses its memory}
\label{tab:memory}
\begin{tabular}{@{}llp{58mm}@{}}
\toprule
Storage & Size & What we use it for \\
\midrule
ROM    & 448~KB & Start-up code. We do not change it. \\
RAM    & 520~KB & The running program and its working data. \\
Flash  & 1.2~MB & Our program. About 81\% full. \\
Sensor & Inside sensor & Fingerprints. Our chip never reads them. \\
\bottomrule
\end{tabular}
\end{table}

\subsectionhead{Input and Output Architecture}

The chip exposes 34 programmable pins, three serial ports capable of up to
5 MBaud, two I2C interfaces and four SPI controllers \parencite{espressif2025}.
Sigurado uses three of those classes and leaves SPI unused.

Table~\ref{tab:io} lists what we connected where. The fingerprint sensor is
given its own serial port because it exchanges packet messages continuously. The
screen uses I2C, which carries a display on two wires
\parencite{espressif2025}. The lock, button, and light need only single pins.

\begin{table}[H]
\centering
\caption{What is connected to which pin}
\label{tab:io}
\begin{tabular}{@{}lllc c@{}}
\toprule
Part & Connection & Door & Cabinet \\
\midrule
Fingerprint sensor & Serial port 2 & 16, 17 & 16, 17 \\
Screen             & I2C           & 21, 22 & 21, 22 \\
Sign-up button     & Pin (in)      & 4      & 4 \\
Status light       & Pin (out)     & 2      & 2 \\
Lock switch        & Pin (out)     & 5      & 5 \\
Door closed sensor & Pin (in)      & ---    & 18 \\
Buzzer             & Pin (out)     & ---    & 19 \\
Text message unit  & Serial port 1 & ---    & 26, 27, 25 \\
\bottomrule
\end{tabular}
\end{table}

The lock pin is the only one that moves something physical. The lock runs on its
own 12~V power, not from the chip. A relay acts as the switch between them. The
door lock stays open for 3 seconds and the cabinet lock for 4. The cabinet also has a small switch that tells us
whether the door really closed.

\subsectionhead{Communication Architecture}

Each reader joins the school Wi-Fi and sends messages to the server. Each reader
has its own ID and password. It does not use a person's login.

This matters. If someone steals a reader and opens it, they only get that
reader's password. They cannot pretend to be a person, and we can change that
one password without touching the other reader. \textcite{rahman2026} name
security setup as a common weak spot on this chip, and this is what it looks
like in practice.

Each reader also says ``I am still here'' every 30 seconds. That is how the
website shows which readers are working. All clocks are set from the internet,
so every record has a matching time.

\sectionhead{Block Diagram}

Figure~\ref{fig:block} shows the two physical units the system is built from.
On the left is the materials cabinet, with its reader set into the panel above
the bins. On the right is the door kiosk, a stand that holds the door reader at
hand height beside the entrance. Each is drawn next to the lumber frame it is
built on, so the finished unit and its skeleton can be compared directly.

\begin{figure}[H]
\centering
\caption{The cabinet and the door kiosk, each beside the frame it is built on}
\label{fig:block}
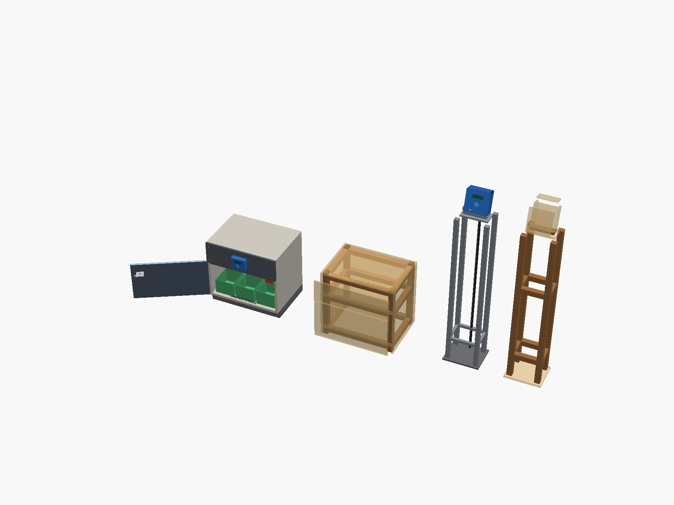
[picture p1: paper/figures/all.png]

\end{figure}

\sectionhead{Hardware Components}

Table~\ref{tab:bom} lists every part used and the job it does. Quantities are per reader unless the entry says otherwise. Nothing on the list is rare or difficult to source, which was deliberate. A part that cannot be replaced from a local shop is a part that ends the project on the day it fails.

\begin{table}[H]
\centering
\caption{Parts used and what each one does}
\label{tab:bom}
\begin{tabular}{@{}p{32mm}p{78mm}@{}}
\toprule
Part & What it does \\
\midrule
ESP32 board &
  The small computer. Runs the program and connects to Wi-Fi. One per reader. \\
Fingerprint sensor (R307 or AS608) &
  Reads a finger and checks it against its own stored list. Fingerprints never
  leave it. \\
Small screen (16 by 2) &
  Shows messages. On the cabinet it also shows the one-time code. \\
Relay and 12~V lock &
  The relay is a switch. The lock runs on its own power, not the chip's. \\
Door switch &
  Cabinet only. Tells us if the door really closed. \\
SIM800L text unit &
  Cabinet only. Sends a text when the cabinet opens or someone is refused. \\
Buzzer, light, button &
  The button starts sign-up. The buzzer warns if the door is left open. \\
\bottomrule
\end{tabular}
\end{table}

\sectionhead{Hardware Architecture Design}

The cabinet and the reader box were drawn as 3D models before building. The
cabinet has three shelves behind locked doors. All the electronics sit in a
hidden space behind a screwed panel, so users never see them.

\begin{figure}[H]
\centering
\caption{The cabinet with its service panel removed, showing the electronics bay
above the materials bins}
\label{fig:3d}
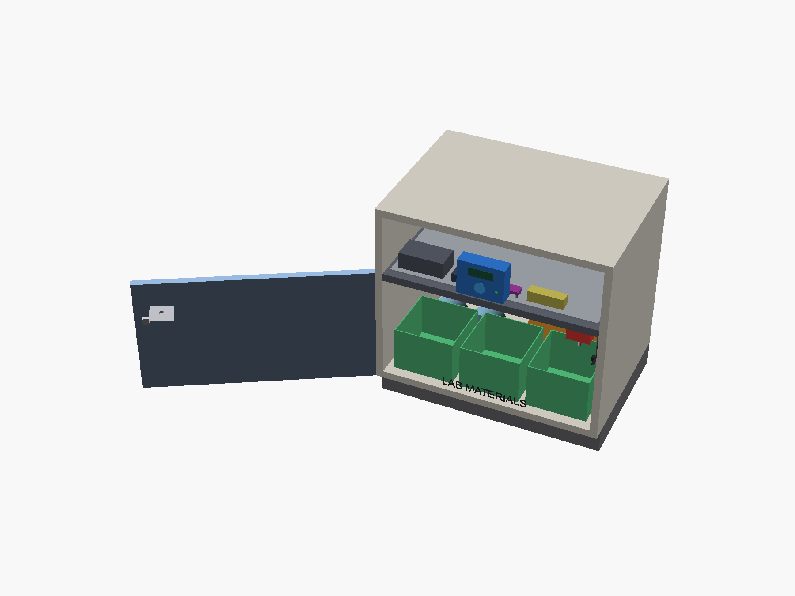
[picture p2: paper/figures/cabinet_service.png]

\end{figure}

Figure~\ref{fig:head} looks inside the reader box itself, with the back plate
taken off. This is the view used to check that every part fits and to plan the
wiring before anything was cut.

\begin{figure}[H]
\centering
\caption{Inside the reader box with the back plate removed, showing the board,
sensor, relay and lock wiring}
\label{fig:head}
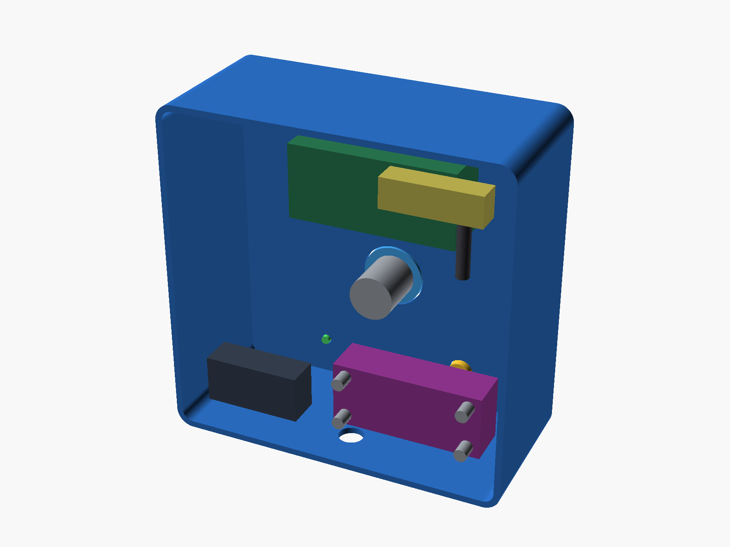
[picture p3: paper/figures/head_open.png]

\end{figure}

Wiring follows Table~\ref{tab:io}. Three rules guide the layout. First, the lock
gets its own power supply, because it pulls a lot of current when it opens and
would otherwise restart the chip. Second, the text unit also gets its own
supply, for the same reason. Third, one wire on the text unit needs a voltage
reducer, because the chip's signal is too strong for it.

\sectionhead{Data Flow}

Data passes through three programs on its way from a finger to the record: the
firmware on the ESP32 readers, the backend server, and the frontend website.
This section first lists the steps of one complete use, then follows the data
through each program in turn, with a flowchart for each. It ends one level
lower, with the instructions the chip itself executes.

\subsectionhead{Steps in One Complete Use}

The sequence below traces one successful use from beginning to end, from the
first finger at the door to the borrowed items appearing in the record. It is
the same path drawn in Figure~\ref{fig:overall}.

\begin{enumerate}
  \item Someone puts a finger on the door sensor. The sensor finds a match and
        gives back a slot number.
  \item The door reader sends that number, plus its own ID and password, to the
        server.
  \item The server looks up the person, starts a 120-second session, saves the
        record, and replies ``allowed''.
  \item The door reader opens the lock for 3 seconds and shows a message.
  \item Someone puts a finger on the cabinet sensor. The cabinet reader sends
        its own request.
  \item The server checks whether this is the same person who has the running
        session. If yes, it makes a one-time code and saves the record. If no,
        it refuses and saves that too.
  \item The cabinet releases its lock for 4 seconds and shows the code. The
        server queues a text message, which the cabinet sends on its next check.
        If the door is left open, the buzzer sounds.
  \item The person types the code and the borrowed items into the website. The
        server accepts it only if the code is still valid.
\end{enumerate}

\subsectionhead{The ESP32 Firmware}

Each reader runs one program that starts once and then repeats a single loop for
as long as it has power. Figure~\ref{fig:firmware} shows the cabinet reader,
which has the most to do. The door reader runs the same loop without the door
switch and the text messages. The only way out of the program is at start-up:
a reader whose fingerprint sensor does not answer shows an error and stops
there, since it has no work to do without one.

\begin{figure}[H]
\centering
\caption{The cabinet reader's firmware: start-up, then one pass of the loop}
\label{fig:firmware}
\input{figures/flow-firmware}
\end{figure}

Each pass of the loop asks a fixed list of questions in the same order: has the
door switch changed, was the enroll button pressed, is there a finger on the
sensor, is a heartbeat due, and are text messages due. Most passes answer no to
all of them and end with a 50 ms wait, so the loop runs about twenty times a
second. The timers are kept by comparing the chip's millisecond clock against
the last time each job ran, rather than by stopping to wait for them.

Two steps do stop the loop while they run: holding the lock open for 4 seconds,
and holding a message on the screen. During those moments the reader cannot take
another finger. The Wi-Fi connection is not affected, because the Wi-Fi stack
runs on the chip's other core.

\subsectionhead{The Backend}

Every scan from either reader arrives at the same address on the server, and
Figure~\ref{fig:backend} shows what the server does with it. The first two
checks apply to both readers: the request must come from a known reader with
the right secret, and the finger must belong to a registered person. After that
the path splits by which reader sent the scan.

\begin{figure}[H]
\centering
\caption{How the backend decides a scan from the door or the cabinet}
\label{fig:backend}
\input{figures/flow-backend}
\end{figure}

A door scan only has to confirm that the account is active, then opens a
session that ends 120 seconds later. A cabinet scan has to find an open session
belonging to the same person. There is no separate ``wrong person'' check,
because the server looks sessions up by the person who just scanned. If someone
else opened the door, the person at the cabinet simply has no session, and the
refusal is recorded as possible tailgating.

Every box in the figure that says ``save'' writes one row to the record. The
server has no route that edits or deletes those rows. Each new row is also
pushed straight to any dashboard that is open, and, if it is an opening or a
refusal, a text message is queued for the people subscribed to that alert.

\subsectionhead{The Frontend}

The website never talks to a reader. Everything it shows comes from the backend,
and everything a person types goes back to it. Figure~\ref{fig:frontend} shows
the checkout page, which is where the cabinet's one-time code is used.

\begin{figure}[H]
\centering
\caption{The checkout page, from opening it to the record being saved}
\label{fig:frontend}
\input{figures/flow-frontend}
\end{figure}

While the page is open it asks the server every 5 seconds whether a code is
waiting. The server answers yes or no and when the code expires, but it never
sends the code itself. The only place the code can be read is the cabinet
screen, so the only way to fill in the form is to have been standing at the
cabinet when it opened. The server checks the code again when the form is sent,
so a code that is guessed, reused, or more than 15 minutes old is refused and
the attempt is recorded.

\subsectionhead{How the Chip Runs the Instructions}

Underneath all of this, the chip repeats one cycle. It fetches an instruction,
works out what it means, and carries it out \parencite{espressif2025}.
Figure~\ref{fig:instruction} shows that cycle. The program itself is stored in
external flash, so an instruction that is not already in the cache has to be
loaded from there first \parencite{espressif2025}.

\begin{figure}[H]
\centering
\caption{The fetch, decode, and execute cycle, with an example of each kind of
instruction from the reader firmware}
\label{fig:instruction}
\input{figures/flow-instruction}
\end{figure}

Three moments from the firmware show the three kinds of instruction at work.

\textbf{Waiting for the sensor.} Each pass of the loop reads the status of
serial port 2 to see whether the sensor has sent anything. That read is a load
from a peripheral register. Most of the time nothing has arrived, and the loop
moves on.

\textbf{Building the message.} To send a scan, the chip copies text into
internal RAM piece by piece until the request is complete. These are loads and
stores to memory, and this is the step that uses the most of it.

\textbf{Opening the lock.} Releasing the lock is one store to the register that
drives pin 5. The chip then waits 4 seconds and makes one more store to close
it again.

\sectionhead{What a Person Sees at the Reader}

The person standing at the door has one screen and two lines of sixteen
characters to work with. That limit shapes every message: there is no room to
explain, so each line has to say one thing. The wording below is taken from the
firmware exactly as it is displayed.

Table~\ref{tab:lcd-door} lists what the door reader shows. When nothing is
happening it rests on its idle message, so anybody walking up already knows what
to do without being told.

\begin{table}[H]
\centering
\caption{What the door reader displays}
\label{tab:lcd-door}
\linespread{1}\selectfont
\begin{tabular}{@{}p{40mm}p{34mm}p{34mm}@{}}
\toprule
Situation & Top line & Bottom line \\
\midrule
Waiting, nobody inside  & \texttt{Sigurado door}  & \texttt{Scan finger} \\
Waiting, session live   & \texttt{Sigurado door}  & \texttt{session 97s} \\
Asking the server       & \texttt{Checking...}    & \texttt{one moment} \\
Allowed in              & \texttt{Welcome}        & their name \\
Finger not signed up    & \texttt{Not registered} & \texttt{Press enroll} \\
Sensor could not read   & \texttt{Did not read}   & \texttt{please try again} \\
No network              & \texttt{No WiFi yet}    & \texttt{check settings} \\
\bottomrule
\end{tabular}
\end{table}

The second row is worth a note. While a session is running, the idle screen
counts it down in place of the usual prompt, so a person crossing the room can
see how long they have left before the cabinet stops recognising them. The
countdown is a hint rather than the rule: the server holds the real clock, and
the reader only displays what it was last told.

Signing up a finger is a separate sequence, shown in
Table~\ref{tab:lcd-enroll}. The sensor needs the same finger presented more than
once to build a usable template, so the screen walks the person through it one
step at a time.

\begin{table}[H]
\centering
\caption{What the door reader displays while a finger is being signed up}
\label{tab:lcd-enroll}
\linespread{1}\selectfont
\begin{tabular}{@{}p{40mm}p{34mm}p{34mm}@{}}
\toprule
Step & Top line & Bottom line \\
\midrule
First impression  & \texttt{Place finger}   & \texttt{hold still} \\
Lift off          & \texttt{Remove finger}  & \texttt{hold still} \\
Second impression & \texttt{Place again}    & \texttt{hold still} \\
Saving it         & \texttt{Saving...}      & \texttt{one moment} \\
Code to claim it  & the code                & \texttt{Type it on site} \\
Claimed           & \texttt{All set}        & their name \\
Sensor is full    & \texttt{Sensor is full} & \texttt{ask an admin} \\
\bottomrule
\end{tabular}
\end{table}
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

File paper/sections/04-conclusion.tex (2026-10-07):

\chapterhead{Conclusion}

\sectionhead{Problems Encountered}

Six problems shaped the final design. The first three appeared in the software, where they were found and corrected. The next two were electrical, and were caught while the readers were being assembled. The last belongs to the room itself.

\subsectionhead{Slot Numbers Meant Different People}
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

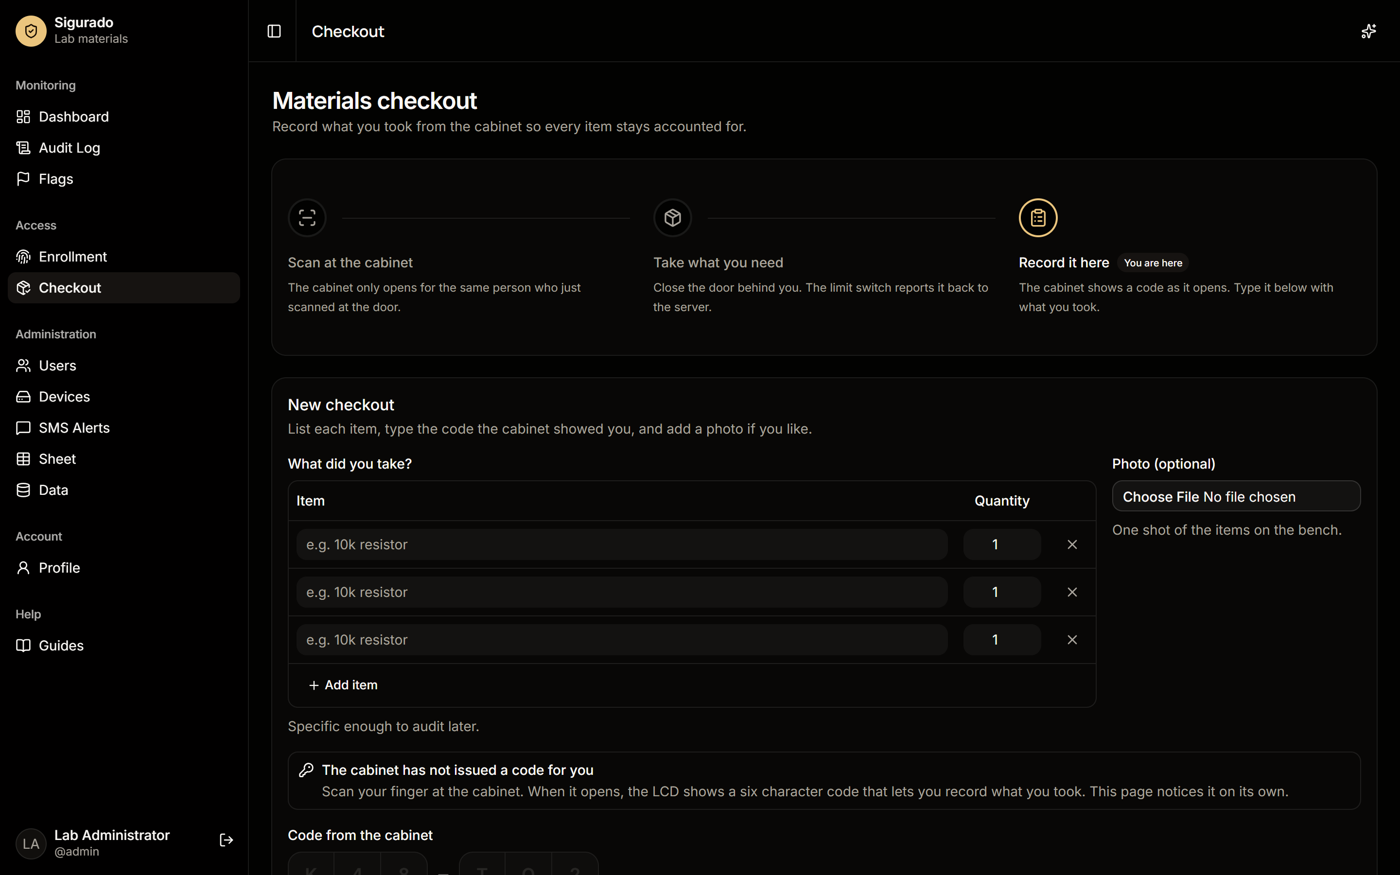
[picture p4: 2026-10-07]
paper/figures/web-checkout.png

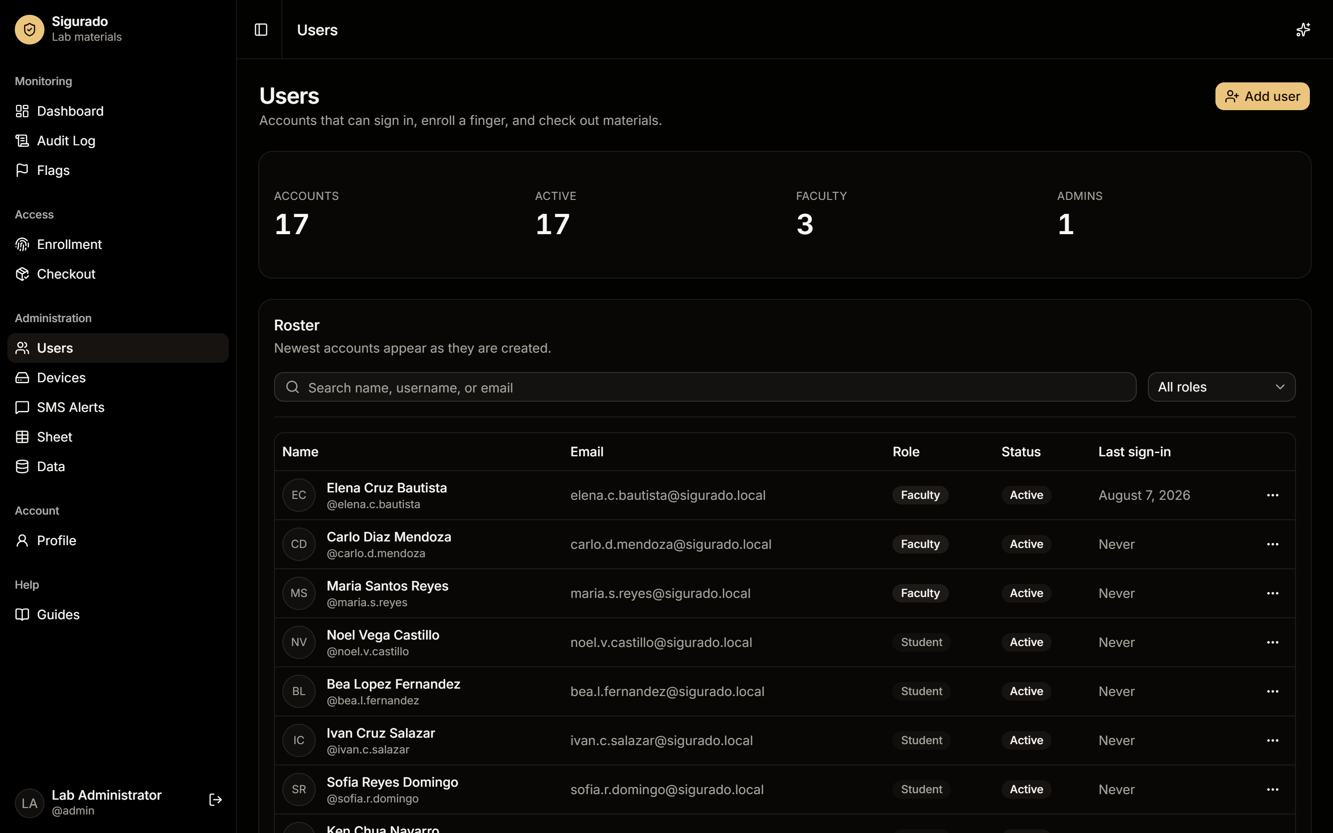
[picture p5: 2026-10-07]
paper/figures/web-users.png

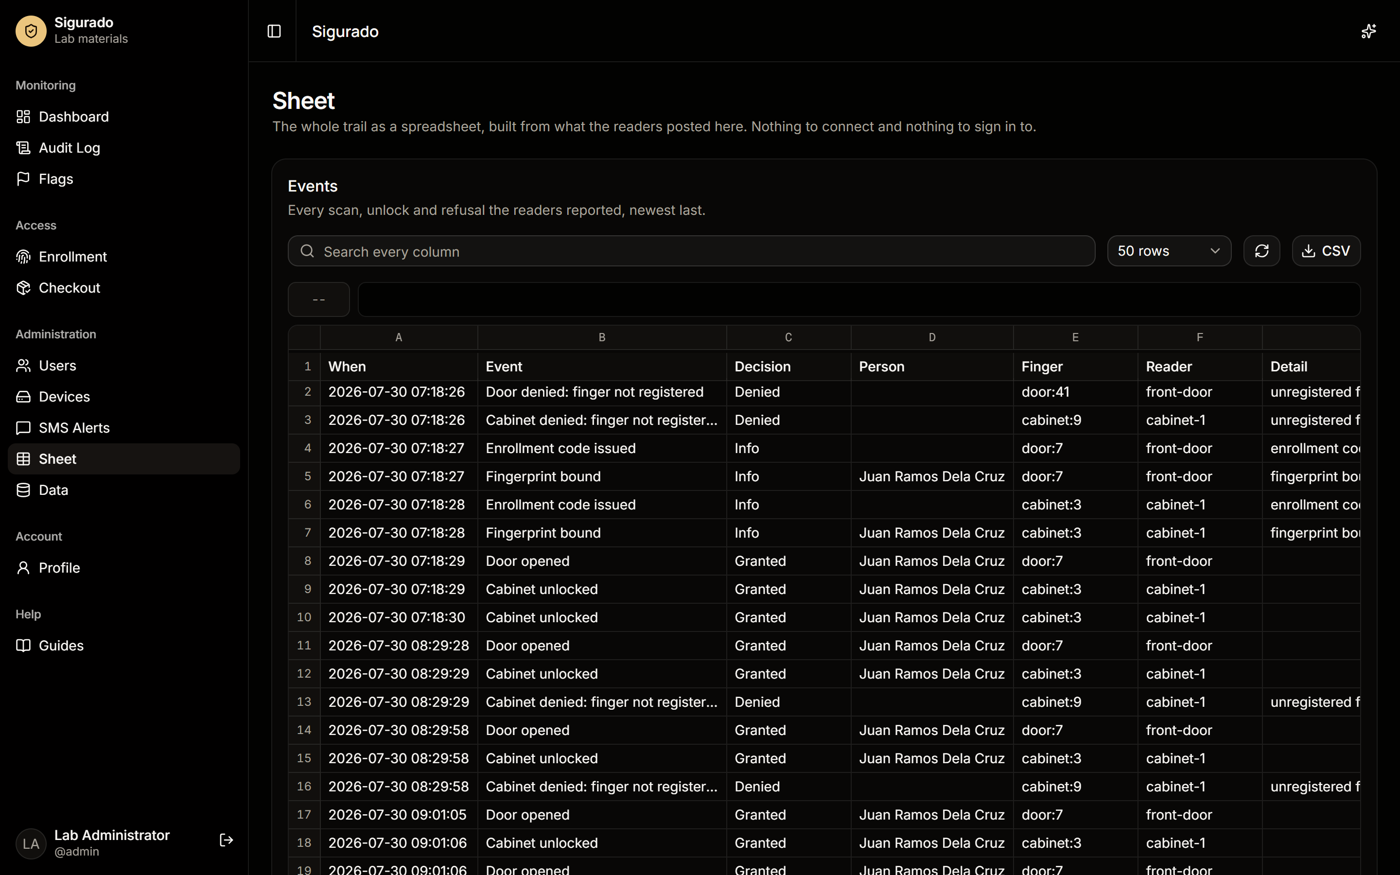
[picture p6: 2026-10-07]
paper/figures/web-sheet.png

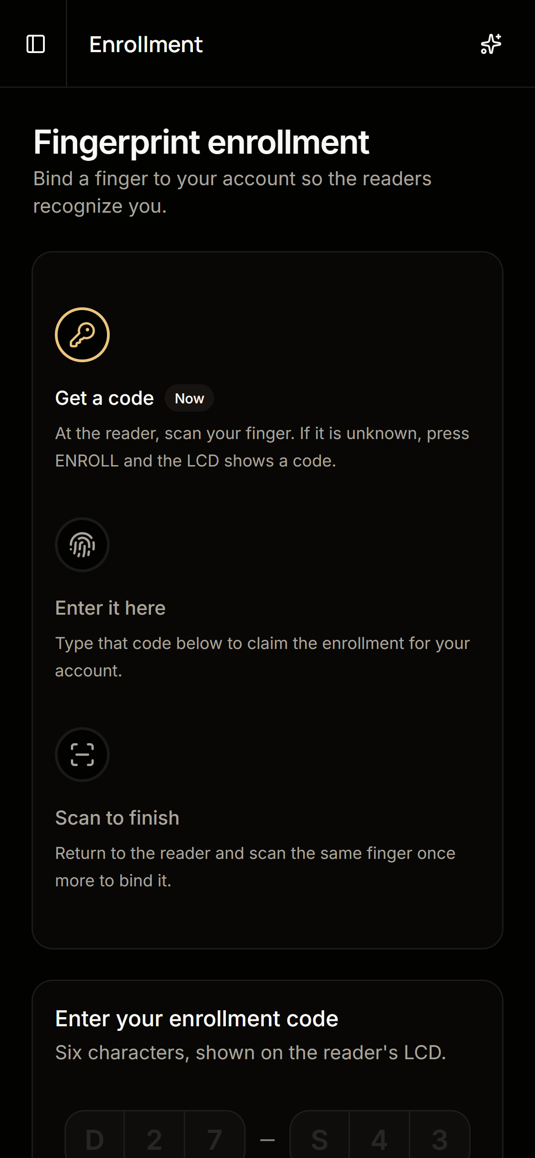
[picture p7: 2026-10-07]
paper/figures/mob-enrollment.png

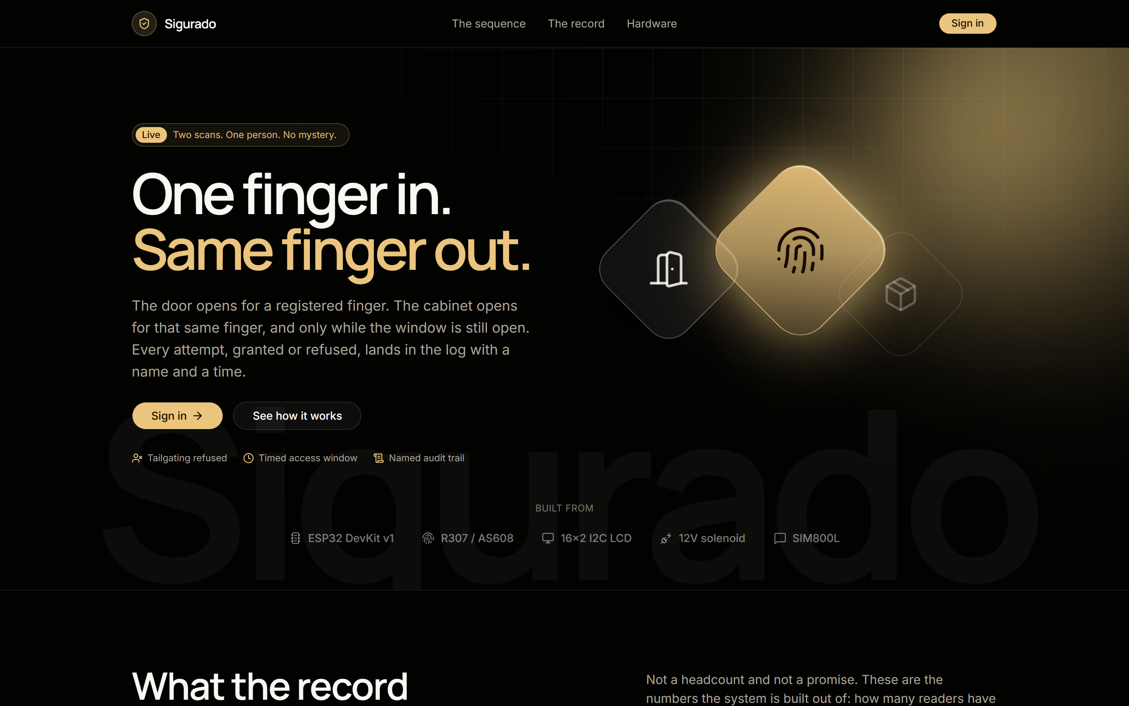
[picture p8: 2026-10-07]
paper/figures/web-landing.png

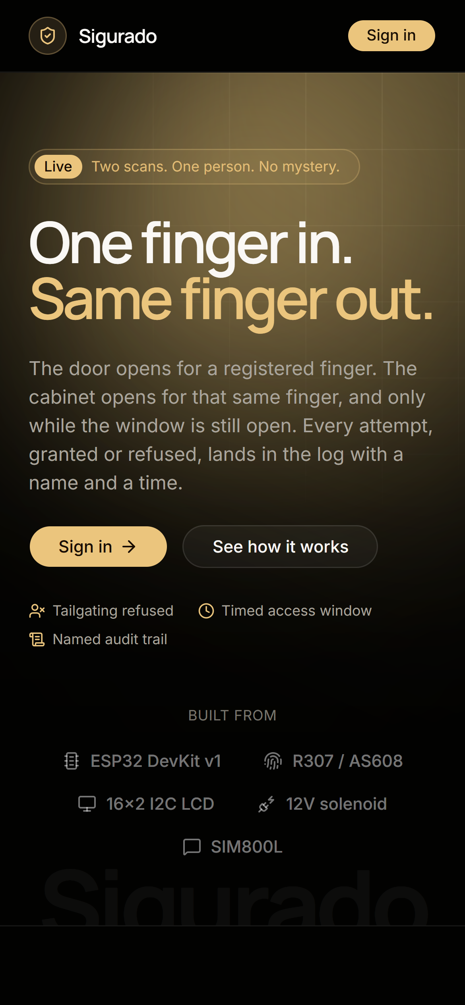
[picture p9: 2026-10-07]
paper/figures/mob-landing.png

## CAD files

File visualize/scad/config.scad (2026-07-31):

// Sigurado 3D models: shared dimensions and colors.
// All units are millimetres.
//   X = width  (0 at the left)
//   Y = depth  (0 at the FRONT, increasing toward the back)
//   Z = height (0 at the floor)

// Curve quality. $fn is left at 0 so the adaptive pair below is used instead:
// $fa caps the angle per facet and $fs the facet length, so a big wire spool
// gets far more segments than a 5 mm LED. Raise HD for smoother, slower.
HD  = 1;              // 1 = smooth, 2 = very smooth, 0.5 = fast/draft
$fn = 0;
$fa = 3 / HD;         // degrees per facet
$fs = 0.7 / HD;       // mm per facet

// ---------------------------------------------------------------- cabinet --
// Prototype: ONE storage slot with one door, one solenoid, one limit switch.
// The overall height is derived from the slot, so changing SLOT_H resizes the
// whole cabinet. Sized to sit on a bench, not on the floor.
CABINET_W = 550;
CABINET_D = 400;
SLOT_H    = 260;   // interior height of the single storage slot

PANEL_T      = 18;
BACK_T       = 12;
PLINTH_H     = 60;
PLINTH_INSET = 30;

SHELF_INSET = 8;

ELEC_BAY_H      = 150;   // concealed service bay across the top
SERVICE_PANEL_T = 15;

DOOR_T        = 18;
DOOR_GAP      = 3;
DOOR_OPEN_DEG = 150;

HANDLE_LEN = 120;
HANDLE_DIA = 14;

LOCK_W = 55; LOCK_D = 40; LOCK_H = 30;
LOCK_BOLT_DIA = 10;
LOCK_BOLT_LEN = 22;

NODE_W = 110; NODE_H = 85; NODE_D = 36;

// Door-state sensing: lever limit switch on the carcass, pressed by a striker
// pad on the door. Without this the server cannot tell "locked" from "bolt shot
// into thin air". Body and lever are sized from a V-153-1C25 style microswitch.
SWITCH_W = 20; SWITCH_D = 11; SWITCH_H = 11;
LEVER_D  = 22; LEVER_W = 6; LEVER_T = 1.5;
STRIKER_W = 16; STRIKER_D = 8; STRIKER_H = 16;

// Latch tab on the door. The far end is ramped so the closing door cams the
// spring bolt up and it drops into the hole on its own: no power needed.
TAB_T      = 6;
TAB_FLAT_D = 30;
TAB_RAMP_D = 20;

PSU      = [110, 62, 40];
RELAY    = [78, 55, 20];
TERMINAL = [85, 26, 26];
MCU      = [63, 25.5, 7];

// -------------------------------------------------- derived cabinet values --
// Stack, bottom to top: plinth -> slot -> divider -> service bay -> top panel.
INTERIOR_X0 = PANEL_T;
INTERIOR_W  = CABINET_W - 2 * PANEL_T;
INTERIOR_D  = CABINET_D - BACK_T;

INTERIOR_Z0 = PLINTH_H + PANEL_T;         // floor of the slot
DIVIDER_Z   = INTERIOR_Z0 + SLOT_H;       // underside of the service divider
ELEC_Z0     = DIVIDER_Z + PANEL_T;        // floor of the service bay
INTERIOR_Z1 = ELEC_Z0 + ELEC_BAY_H;
CABINET_H   = INTERIOR_Z1 + PANEL_T;

SHELF_Z = [];   // no shelves: the prototype is a single open slot

DOOR_COUNT = 1;
DOOR_H     = ELEC_Z0 - PLINTH_H - DOOR_GAP;
DOOR_Z     = [PLINTH_H];

SENSE_Z = INTERIOR_Z0 + SLOT_H * 0.65;    // switch and striker height

// ---------------------------------------------------------- scanner unit --
// Sized from the real modules below, not guessed. The old 150 x 115 x 55 box
// could not hold a 16x2 LCD module (80 x 36, and 26 deep with its I2C backpack)
// and an ESP32 with pin headers at the same time, so it grew.
SU_W = 160; SU_H = 160; SU_D = 70;
SU_WALL         = 3;
SU_FILLET       = 8;
SU_BACKPLATE_T  = 3;

// Real module footprints, [width, depth, height] as mounted.
MOD_LCD  = [80, 26, 36];    // LCD1602 + I2C backpack
MOD_ESP  = [70, 20, 30];    // ESP32-S3 DevKitC, headers included
MOD_BUCK = [45, 16, 22];    // 12V -> 5V buck converter
MOD_TERM = [45, 12, 14];    // screw terminal block

FP_DIA      = 30;     // R307 face, i.e. the panel cutout
FP_BODY_DIA = 21;     // barrel behind the panel
FP_BODY_D   = 25;
FP_Z_FRAC   = 0.40;

LCD_W      = 71.5;    // viewing area, i.e. the panel window
LCD_H      = 24.5;
LCD_Z_FRAC = 0.72;

BTN_DIA    = 12;
LED_DIA    = 5;
BTN_Z_FRAC = 0.13;
GLAND_DIA  = 12;
MOUNT_HOLE_DIA = 4.5;

STANDOFF_DIA = 6;
STANDOFF_H   = 8;

// ------------------------------------------------- floor stand (4 legs) --
STAND_H   = 1150;     // top of the legs
LEG       = 30;
BASE_W    = 260;
BASE_D    = 220;
BASE_T    = 12;
LEG_INSET = 14;
TOP_PLATE_W = 190;
TOP_PLATE_D = 100;
TOP_PLATE_T = 12;
RAIL        = 20;
RAIL_Z      = 170;
CONDUIT_DIA = 18;
HEAD_TILT   = 15;     // degrees, tips the face up toward the user

// ------------------------------------------------- construction / framing --
// Sizes for the "how to build it" views.
LUMBER  = 38;   // nominal 2x2 lumber, dressed (38 x 38 mm)
SKIN_T  = 12;   // plywood skin: sides, back, top, doors
SHELF_T = 18;   // plywood shelves and the service divider
PLY_ALPHA = 0.40;
EXPLODE   = 90; // how far the doors and panels are pulled off in build views

C_LUMBER = [0.62, 0.42, 0.24];
C_PLY    = [0.86, 0.72, 0.48];

// ----------------------------------------------------------- presentation --
SHOW_LABELS = true;
LABEL_SIZE  = 20;
LABEL_DEPTH = 1.5;
LABEL_FONT  = "Arial";

C_CARCASS  = [0.80, 0.78, 0.74];
C_SHELF    = [0.70, 0.68, 0.65];
C_BACK     = [0.66, 0.64, 0.61];
C_PLINTH   = [0.42, 0.42, 0.44];
C_DOOR     = [0.60, 0.73, 0.88];
C_HANDLE   = [0.55, 0.57, 0.60];
C_LOCK     = [0.85, 0.22, 0.20];
C_BOLT     = [0.75, 0.75, 0.78];
C_ENCL     = [0.16, 0.42, 0.75];
C_SENSOR   = [0.25, 0.62, 0.90];
C_LCD      = [0.10, 0.32, 0.22];
C_BUTTON   = [0.95, 0.75, 0.20];
C_LED      = [0.30, 0.85, 0.40];
C_BOARD    = [0.15, 0.45, 0.30];
C_MCU      = [0.55, 0.20, 0.55];
C_LABEL    = [0.15, 0.15, 0.17];
C_SERVICE  = [0.34, 0.36, 0.40];
C_PSU      = [0.30, 0.32, 0.36];
C_RELAY    = [0.20, 0.24, 0.30];
C_TERMINAL = [0.72, 0.68, 0.30];
C_PLATE    = [0.58, 0.60, 0.63];
C_WIRE     = [0.25, 0.25, 0.28];
C_SWITCH   = [0.14, 0.14, 0.16];
C_STRIKER  = [0.82, 0.82, 0.86];

C_MAT_COMPONENTS = [0.30, 0.70, 0.45];
C_MAT_INSTRUMENTS = [0.95, 0.62, 0.20];
C_MAT_BULK        = [0.45, 0.60, 0.70];

SLOT_LABEL = "LAB MATERIALS";

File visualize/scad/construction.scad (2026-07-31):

// Build views: the 2x2 lumber skeleton with the plywood shown semi-transparent
// on top of it, so you can see which piece goes where.
//
//   dark brown = 2x2 lumber (38 x 38 mm dressed)
//   pale tan   = plywood (12 mm skin, 18 mm shelves)
//
// Doors and loose panels are pulled forward so they read as separate parts.

include <parts.scad>

module lumber(w, d, h, x, y, z) {
    color(C_LUMBER) box_at(w, d, h, x, y, z);
}

module ply(w, d, h, x, y, z) {
    color([C_PLY[0], C_PLY[1], C_PLY[2], PLY_ALPHA]) box_at(w, d, h, x, y, z);
}

// ------------------------------------------------------------- cabinet ------
POST_X = [SKIN_T, CABINET_W - SKIN_T - LUMBER];
POST_Y = [SKIN_T, CABINET_D - SKIN_T - LUMBER];

RAIL_SPAN_X = POST_X[1] - (POST_X[0] + LUMBER);
RAIL_SPAN_Y = POST_Y[1] - (POST_Y[0] + LUMBER);

FLOOR_Z = INTERIOR_Z0 - SHELF_T;

// One rectangle of 2x2 rails at height z, tying the four posts together.
module rail_ring(z) {
    for (y = POST_Y)
        lumber(RAIL_SPAN_X, LUMBER, LUMBER, POST_X[0] + LUMBER, y, z);
    for (x = POST_X)
        lumber(LUMBER, RAIL_SPAN_Y, LUMBER, x, POST_Y[0] + LUMBER, z);
}

module cabinet_frame(explode = true) {
    off = explode ? EXPLODE : 0;

    // four corner posts, floor to top
    for (x = POST_X, y = POST_Y)
        lumber(LUMBER, LUMBER, CABINET_H, x, y, 0);

    // rails: one ring under every horizontal panel
    rail_ring(FLOOR_Z - LUMBER);
    for (z = SHELF_Z) rail_ring(z - LUMBER);
    rail_ring(DIVIDER_Z - LUMBER);
    rail_ring(CABINET_H - SKIN_T - LUMBER);

    // plywood carcass
    ply(SKIN_T, CABINET_D, CABINET_H, 0, 0, 0);
    ply(SKIN_T, CABINET_D, CABINET_H, CABINET_W - SKIN_T, 0, 0);
    ply(CABINET_W - 2 * SKIN_T, SKIN_T, CABINET_H, SKIN_T, CABINET_D - SKIN_T, 0);
    ply(CABINET_W - 2 * SKIN_T, CABINET_D - SKIN_T, SKIN_T,
        SKIN_T, 0, CABINET_H - SKIN_T);

    // toe kick
    ply(CABINET_W - 2 * SKIN_T, SKIN_T, PLINTH_H, SKIN_T, PLINTH_INSET, 0);

    // horizontal plywood: floor, shelves, service divider
    ply(CABINET_W - 2 * SKIN_T, CABINET_D - SKIN_T, SHELF_T, SKIN_T, 0, FLOOR_Z);
    for (z = SHELF_Z)
        ply(CABINET_W - 2 * SKIN_T, CABINET_D - SKIN_T - SHELF_INSET, SHELF_T,
            SKIN_T, SHELF_INSET, z);
    ply(CABINET_W - 2 * SKIN_T, CABINET_D - SKIN_T, SHELF_T,
        SKIN_T, 0, DIVIDER_Z);

    // three doors and the service panel, pulled forward off the front
    for (i = [0 : DOOR_COUNT - 1])
        ply(CABINET_W, SKIN_T, DOOR_H, 0, -SKIN_T - off, DOOR_Z[i]);
    ply(CABINET_W, SKIN_T, CABINET_H - ELEC_Z0,
        0, -SKIN_T - off, ELEC_Z0);
}

// --------------------------------------------------------------- kiosk ------
KIOSK_LEG_X = [-BASE_W / 2 + LEG_INSET, BASE_W / 2 - LEG_INSET - LUMBER];
KIOSK_LEG_Y = [-BASE_D / 2 + LEG_INSET, BASE_D / 2 - LEG_INSET - LUMBER];

module kiosk_rail_ring(z) {
    span_x = KIOSK_LEG_X[1] - (KIOSK_LEG_X[0] + LUMBER);
    span_y = KIOSK_LEG_Y[1] - (KIOSK_LEG_Y[0] + LUMBER);
    for (y = KIOSK_LEG_Y)
        lumber(span_x, LUMBER, LUMBER, KIOSK_LEG_X[0] + LUMBER, y, z);
    for (x = KIOSK_LEG_X)
        lumber(LUMBER, span_y, LUMBER, x, KIOSK_LEG_Y[0] + LUMBER, z);
}

module kiosk_frame(explode = true) {
    off = explode ? EXPLODE : 0;
    lift = SU_D * tan(HEAD_TILT);

    // plywood base
    ply(BASE_W, BASE_D, SHELF_T, -BASE_W / 2, -BASE_D / 2, 0);

    // four 2x2 legs
    for (x = KIOSK_LEG_X, y = KIOSK_LEG_Y)
        lumber(LUMBER, LUMBER, STAND_H - SHELF_T, x, y, SHELF_T);

    // two rail rings brace the tall post
    kiosk_rail_ring(RAIL_Z);
    kiosk_rail_ring(STAND_H * 0.62);

    // plywood top plate and the tilt wedge
    ply(TOP_PLATE_W, TOP_PLATE_D, SHELF_T,
        -TOP_PLATE_W / 2, -TOP_PLATE_D / 2, STAND_H);
    color(C_LUMBER)
        translate([-SU_W / 2, -30, STAND_H + SHELF_T]) wedge(SU_W, SU_D, lift);

    // head as a plywood shell, lid pulled up so the inside is visible
    translate([-SU_W / 2, -30, STAND_H + SHELF_T])
        translate([0, SU_D, 0]) rotate([-HEAD_TILT, 0, 0]) translate([0, -SU_D, 0]) {
            ply(SKIN_T, SU_D, SU_H, 0, 0, 0);
            ply(SKIN_T, SU_D, SU_H, SU_W - SKIN_T, 0, 0);
            ply(SU_W - 2 * SKIN_T, SU_D, SKIN_T, SKIN_T, 0, 0);
            ply(SU_W - 2 * SKIN_T, SKIN_T, SU_H - 2 * SKIN_T,
                SKIN_T, SU_D - SKIN_T, SKIN_T);
            // face panel, pulled off the front
            ply(SU_W, SKIN_T, SU_H, 0, -SKIN_T - off, 0);
            // top panel, lifted clear
            ply(SU_W - 2 * SKIN_T, SU_D, SKIN_T,
                SKIN_T, 0, SU_H - SKIN_T + off * 0.5);
        }
}

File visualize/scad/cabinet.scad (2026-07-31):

// Model A: the Sigurado storage cabinet.
//
// Bottom to top: plinth -> 3 material compartments behind lockable double
// doors -> a CONCEALED SERVICE BAY behind a screwed panel. Every electronic
// part lives in that bay, so the end user only ever sees the material shelves.

include <parts.scad>

module cabinet_carcass() {
    color(C_PLINTH)
        box_at(CABINET_W, CABINET_D - PLINTH_INSET, PLINTH_H, 0, PLINTH_INSET, 0);

    color(C_CARCASS) {
        box_at(CABINET_W, CABINET_D, PANEL_T, 0, 0, PLINTH_H);
        box_at(CABINET_W, CABINET_D, PANEL_T, 0, 0, CABINET_H - PANEL_T);
        box_at(PANEL_T, CABINET_D, INTERIOR_Z1 - INTERIOR_Z0, 0, 0, INTERIOR_Z0);
        box_at(PANEL_T, CABINET_D, INTERIOR_Z1 - INTERIOR_Z0,
               CABINET_W - PANEL_T, 0, INTERIOR_Z0);
    }

    color(C_BACK)
        box_at(INTERIOR_W, BACK_T, INTERIOR_Z1 - INTERIOR_Z0,
               INTERIOR_X0, CABINET_D - BACK_T, INTERIOR_Z0);

    // sealed divider between the user storage and the electronics bay
    color(C_SERVICE)
        box_at(INTERIOR_W, INTERIOR_D, PANEL_T, INTERIOR_X0, 0, DIVIDER_Z);

    color(C_SHELF)
        for (z = SHELF_Z)
            box_at(INTERIOR_W, INTERIOR_D - SHELF_INSET, PANEL_T,
                   INTERIOR_X0, SHELF_INSET, z);
}

module cabinet_service_bay() {
    plate_z = ELEC_Z0;
    z = ELEC_Z0 + 4;
    y = 34;
    x_psu      = INTERIOR_X0 + 24;
    x_relay    = x_psu + PSU[0] + 20;
    x_mcu      = x_relay + RELAY[0] + 20;
    x_terminal = x_mcu + MCU[0] + 20;
    board_z    = z + 8;

    color(C_PLATE)
        box_at(INTERIOR_W - 20, INTERIOR_D - 40, 4, INTERIOR_X0 + 10, 20, plate_z);

    color(C_PSU)      box_at(PSU[0], PSU[1], PSU[2], x_psu, y, z);
    color(C_RELAY)    box_at(RELAY[0], RELAY[1], RELAY[2], x_relay, y, z);
    color(C_MCU)      box_at(MCU[0], MCU[1], MCU[2], x_mcu, y, board_z);
    color(C_TERMINAL) box_at(TERMINAL[0], TERMINAL[1], TERMINAL[2], x_terminal, y, z);

    color(C_PLATE)
        for (dx = [5, MCU[0] - 5], dy = [4, MCU[1] - 4])
            cyl_z(3, 8, x_mcu + dx, y + dy, z);

    color(C_WIRE) {
        cyl_x(9, INTERIOR_W - 40, INTERIOR_X0 + 20, INTERIOR_D - 40, z + 26);
        cyl_z(5, 46, CABINET_W / 2, INTERIOR_D - 40, DIVIDER_Z - 44);
    }
}

module cabinet_service_panel() {
    bay_h = CABINET_H - ELEC_Z0;

    color(C_SERVICE)
        box_at(CABINET_W, SERVICE_PANEL_T, bay_h, 0, -SERVICE_PANEL_T, ELEC_Z0);

    color(C_HANDLE)
        for (x = [26, CABINET_W - 26], z = [ELEC_Z0 + 26, CABINET_H - 30])
            cyl_y(4, 6, x, -SERVICE_PANEL_T - 2, z);

    // sits low on the panel so the scanner mounted on top of it stays clear
    if (SHOW_LABELS)
        color(C_LABEL)
            front_label("ELECTRONICS - NO USER ACCESS", CABINET_W / 2,
                        ELEC_Z0 + 11, 11);
}

LOCK_X = CABINET_W - PANEL_T - LOCK_W - 20;
LOCK_Y = 6;
LOCK_Z = DIVIDER_Z - LOCK_H;
BOLT_X = LOCK_X + LOCK_W / 2;
BOLT_Y = LOCK_Y + LOCK_D / 2;

// A single 12V solenoid, fail-secure: de-energised means the bolt is out.
// It hangs under the service divider at the door's free edge and throws its
// bolt down through the latch tab on the inside of the door.
module cabinet_lock() {
    color(C_LOCK) box_at(LOCK_W, LOCK_D, LOCK_H, LOCK_X, LOCK_Y, LOCK_Z);
    color(C_BOLT)
        cyl_z(LOCK_BOLT_DIA / 2, LOCK_BOLT_LEN,
              BOLT_X, BOLT_Y, LOCK_Z - LOCK_BOLT_LEN);
}

// Limit switch on the inside of the right panel, opposite the hinge, where a
// door is most likely to sit ajar. Its lever faces the door opening, so the
// closing door presses it through the striker pad on the door itself.
module cabinet_limit_switch() {
    x = CABINET_W - PANEL_T - SWITCH_W;
    body_y = STRIKER_D + LEVER_D;

    color(C_SWITCH) box_at(SWITCH_W, SWITCH_D, SWITCH_H, x, body_y, SENSE_Z);

    // The lever reaches back toward the door, where the striker meets it.
    color(C_SWITCH)
        box_at(LEVER_W, LEVER_D, LEVER_T,
               x + (SWITCH_W - LEVER_W) / 2, STRIKER_D,
               SENSE_Z + SWITCH_H - LEVER_T * 2);

    color(C_WIRE)
        cyl_z(2.5, DIVIDER_Z - SENSE_Z - SWITCH_H,
              x + SWITCH_W / 2, body_y + SWITCH_D / 2, SENSE_Z + SWITCH_H);
}

// Scan-at-the-box unit, mounted on the FRONT of the service panel, centred.
// It sits directly on the face of the concealed bay, so the sensor and relay
// wiring passes straight through into the electronics behind it.
module cabinet_box_node() {
    bay_h = CABINET_H - ELEC_Z0;
    x0 = CABINET_W / 2 - NODE_W / 2;
    y0 = -SERVICE_PANEL_T - NODE_D;
    z0 = ELEC_Z0 + (bay_h - NODE_H) / 2;
    cx = CABINET_W / 2;

    color(C_ENCL)   box_at(NODE_W, NODE_D, NODE_H, x0, y0, z0);
    color(C_SENSOR) cyl_y(13, 5, cx, y0 - 2, z0 + NODE_H * 0.32);
    color(C_LCD)    box_at(58, 3, 20, cx - 29, y0 - 1, z0 + NODE_H * 0.62);
    color(C_LED)    cyl_y(3, 4, cx + 38, y0 - 1, z0 + NODE_H * 0.32);
}

// A single slot, so the materials share it: parts bins across the front, a
// couple of wire spools and a kit box behind them.
module cabinet_materials() {
    gap = 18;
    z = INTERIOR_Z0;
    x0 = INTERIOR_X0 + gap;
    usable_w = INTERIOR_W - 2 * gap;
    front_d = (INTERIOR_D - gap) * 0.42;
    back_y = SHELF_INSET + gap + front_d + gap;

    bw = (usable_w - 2 * gap) / 3;
    color(C_MAT_COMPONENTS)
        for (col = [0 : 2])
            tray(bw, front_d, 110, x0 + col * (bw + gap), SHELF_INSET + gap, z);

    color(C_MAT_BULK)
        for (col = [0 : 1])
            cyl_y(42, 50, x0 + 55 + col * 100, back_y, z + 42);

    color(C_MAT_INSTRUMENTS)
        box_at(usable_w * 0.44, INTERIOR_D - back_y - 10, 140,
               x0 + usable_w * 0.56, back_y, z);
}

module cabinet_labels() {
    if (SHOW_LABELS)
        color(C_LABEL)
            front_label(SLOT_LABEL, CABINET_W / 2, INTERIOR_Z0 + 14);
}

// The door: hinged on the left, handle and latch tab on the right. The tab is
// ramped at its far end, so swinging the door shut cams the spring bolt up and
// lets it drop into the hole. That means closing never needs power, and the
// striker pad beside it presses the limit switch so the server knows the door is
// really home.
module cabinet_door(i) {
    z0 = DOOR_Z[i];
    handle_len = min(HANDLE_LEN, DOOR_H * 0.28);
    handle_x = CABINET_W - 42;
    handle_z = z0 + DOOR_H / 2 - handle_len / 2;
    tab_z = LOCK_Z - LOCK_BOLT_LEN;

    color(C_DOOR) box_at(CABINET_W, DOOR_T, DOOR_H, 0, -DOOR_T, z0);

    color(C_BOLT) {
        difference() {
            box_at(LOCK_W, TAB_FLAT_D, TAB_T, LOCK_X, 0, tab_z);
            cyl_z(LOCK_BOLT_DIA / 2 + 1, TAB_T + 4, BOLT_X, BOLT_Y, tab_z - 2);
        }
        translate([LOCK_X, TAB_FLAT_D, tab_z])
            wedge(LOCK_W, TAB_RAMP_D, TAB_T);
    }

    // Flat pad rather than the bare door edge, so the lever is pressed square on
    // and does not wear a groove in the door.
    color(C_STRIKER)
        box_at(STRIKER_W, STRIKER_D, STRIKER_H,
               CABINET_W - PANEL_T - STRIKER_W, 0, SENSE_Z);

    color(C_HANDLE) {
        cyl_z(HANDLE_DIA / 2, handle_len, handle_x, -DOOR_T - 24, handle_z);
        for (dz = [0, handle_len])
            cyl_y(6, 24, handle_x, -DOOR_T - 24, handle_z + dz);
    }
}

module cabinet(open_doors = true, service_open = false) {
    angle = open_doors ? DOOR_OPEN_DEG : 0;

    cabinet_carcass();
    cabinet_service_bay();
    if (!service_open) cabinet_service_panel();
    cabinet_lock();
    cabinet_limit_switch();
    cabinet_box_node();
    cabinet_materials();
    cabinet_labels();

    for (i = [0 : DOOR_COUNT - 1])
        rotate([0, 0, -angle]) cabinet_door(i);
}

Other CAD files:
visualize/scad/main.scad
visualize/scad/parts.scad
visualize/scad/scanner_unit.scad

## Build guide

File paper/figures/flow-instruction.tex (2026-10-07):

\begin{tikzpicture}[flow, x=1mm, y=1mm,
  end/.style = {term, minimum width=14mm}]

\node[term] (rst)  at (0,14)   {Start};
\node[proc] (pc)   at (0,0)    {Next address in the\\program counter};
\node[dec]  (hit)  at (0,-17)  {In cache\\or IRAM?};
\node[proc] (fill) at (40,-17) {Cache loads a line\\from external flash};
\node[proc] (fet)  at (0,-35)  {Fetch the instruction};
\node[proc] (dcd)  at (0,-49)  {Decode opcode\\and registers};
\node[dec]  (kind) at (0,-66)  {Kind of\\instruction?};
\node[proc] (alu)  at (-36,-85) {Arithmetic in\\registers (ALU)\\e.g. timer checks};
\node[proc] (ram)  at (0,-85)   {Load or store\\in internal RAM\\e.g. the request};
\node[proc] (per)  at (36,-85)  {Load or store to a\\peripheral register\\e.g. UART2, GPIO 5};
\node[proc] (adv)  at (0,-104)  {Write the result,\\advance the counter};
\node[dec]  (pwr)  at (0,-121)  {Power\\still on?};
\node[end]  (x1)   at (0,-138)  {Stop};

\draw[arr] (rst.south) -- (pc.north);
\draw[arr] (pc.south) -- (hit.north);
\draw[arr] (hit.east) -- node[lbl, above] {no} (fill.west);
\draw[arr] (fill.south) |- (0,-27);
\draw[arr] (hit.south) -- node[lbl, left, pos=0.3] {yes} (fet.north);
\draw[arr] (fet.south) -- (dcd.north);
\draw[arr] (dcd.south) -- (kind.north);
\draw[arr] (kind.west) -| node[lbl, above, pos=0.3] {arithmetic} (alu.north);
\draw[arr] (kind.south) -- node[lbl, right] {memory} (ram.north);
\draw[arr] (kind.east) -| node[lbl, above, pos=0.3] {peripheral} (per.north);
\draw[arr] (alu.south) |- (adv.west);
\draw[arr] (ram.south) -- (adv.north);
\draw[arr] (per.south) |- (adv.east);
\draw[arr] (adv.south) -- (pwr.north);
\draw[arr] (pwr.west) -- node[lbl, above, pos=0.2] {yes} (-56,-121) |- (pc.west);
\draw[arr] (pwr.south) -- node[lbl, right] {no} (x1.north);

\end{tikzpicture}

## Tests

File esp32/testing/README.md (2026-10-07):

# Component tests

One sketch per part, so a fault is found in the part you just wired rather than
somewhere in the whole system. Each sketch is self contained: it declares its
own pins at the top, uses nothing from `door/` or `cabinet/`, and prints its own
wiring notes and instructions over serial when it starts.

Work down the list. Nothing below depends on anything above it except where
said, but the order is the one that isolates faults fastest: it proves the board
before the bus, the bus before the display, and the network before the server.

| # | Sketch | What it proves | Node |
|---|---|---|---|
| 1 | `board_check` | The cable, driver, upload path and monitor all work | both |
| 2 | `i2c_scan` | The display answers, and at which address | both |
| 3 | `lcd` | All four rows are readable, and nothing overruns 20 columns | both |
| 4 | `button_led` | The enroll button debounces and the LED follows it | both |
| 5 | `fingerprint` | The AS608 handshakes, enrolls, searches and deletes, with every prompt on the display too | both |
| 6 | `limit_switch` | The door sensor reads shut and open, and which polarity to configure | cabinet |
| 7 | `relay_lock` | The relay clicks, and which way round to drive it | both |
| 8 | `buzzer` | Each alert pattern, and whether the buzzer is active or passive | cabinet |
| 9 | `wifi` | It joins the network, with enough signal where it will be mounted | both |
| 10 | `backend_ping` | The Rust backend accepts this reader's id and secret | both |
| 11 | `gsm_sms` | The SIM800L registers and can send a text | cabinet |
| 12 | `bench_all` | Everything at once, as one pass or fail table | both |

## Running one

From `esp32/tools`, pass the folder name to the uploader for whichever node the
board is going to be:

```
Upload-Door.cmd fingerprint
Upload-Cabinet.cmd limit_switch
```

That flashes the sketch and leaves the board running it. Open the monitor to
drive it:

```
Monitor-Door.cmd
```

Most sketches take single letter commands, listed when they start and again if
you type anything they do not recognize. Nothing needs to be typed for the
sketches that only watch a pin.

Or open the `.ino` in the Arduino IDE, pick **DOIT ESP32 DEVKIT V1**, and use the
IDE's own monitor at 115200.

## Putting the firmware back

These sketches replace the firmware while they are on the board. Nothing is
lost: reflash it when you are done.

```
Upload-Door.cmd
Upload-Cabinet.cmd
```

The fingerprint sensor is the one thing a reflash does not touch. It keeps its
templates in its own flash, so enrollments survive both these tests and any
number of uploads. The only thing that clears them is `x` in the `fingerprint`
sketch.

## Settings

Tests 9 to 12 need the network and, for 10 and 12, the reader's credentials.
Fill them in at the top of each sketch. They are separate from `Config.h` on
purpose, so trying a setting here never disturbs the real firmware.

Get the device id and secret from the web app under **Admin > Devices**. The
secret is shown once, when you create the device, and cannot be read back.

## Two things that catch everybody

**Power.** Each part wants a different supply, and getting one wrong is the most
common way to lose an afternoon.

| Part | Supply |
|---|---|
| AS608 fingerprint sensor | `3V3`. It is a 3.3V module and `VIN` will damage it |
| 20x4 display backpack | `VIN`, which is 5V. It will not light properly on 3.3V |
| Solenoid lock | its own 12V supply, through the relay contacts |
| SIM800L | its own 4V supply, 2A capable, with a big capacitor at the module |

The R307 is sold under the same description as the AS608 but is a 5V part, so
check which one you have before moving the red wire. Trying to run the solenoid
or the modem off the board browns it out and reboots it mid scan.

**The display size.** The backpack is the same PCF8574 chip on a 16x2 and a
20x4, so the I2C address says nothing about how big the glass is. The sketches
here are set for 20x4. If rows 3 and 4 stay blank, press `z` in the `lcd` test
to switch, and change `LCD_COLS` and `LCD_ROWS` at the top of the sketches.

**The 2.4 GHz band.** The ESP32 radio has no 5 GHz. If the router publishes one
name for both bands, the join fails with nothing useful in the log. Test 9 lists
every network it can see, which is the quickest way to tell.

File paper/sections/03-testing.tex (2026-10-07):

\chapterhead{Testing and Performance}

Testing ran at three levels. Unit tests checked the decision logic on its own.
Integration tests checked that the website and the server agree with each other.
System tests exercised the assembled hardware end to end, from a finger at the
door to a borrowed item appearing in the record.

One limit applies to everything below. The tests establish that each behaviour
happens, not how fast or how reliably it happens over many attempts. Timing and
error rates were not recorded across a controlled set of trials, so the rows
marked \textbf{[MEASURE]} in Table~\ref{tab:results} and
Table~\ref{tab:timing} are left for that work.

\sectionhead{Unit and Integration Testing}

Unit testing means checking small pieces of code one at a time. We wrote 18 of
these tests for the server, where the decisions are made. They cover three
things: that passwords follow the rules, that the warning checks work on a quiet
record as well as a busy one, and that the date maths is right.

Integration testing means checking that two parts agree with each other. The
website is checked against the server automatically. That check passed with no
errors across 4{,}871 files. This catches the case where the server starts
sending something the website does not expect.

The reader firmware was compiled for the target board before flashing. Both
programs built with no errors, which confirmed that the modules link correctly
and that the libraries match the board.

\sectionhead{System Testing}

System testing means using the whole thing the way a person would. We ran the
server and the website together against a database that already held records.
This matters. An empty database returns nothing, so a fault that only appears
with real data would stay hidden.

We logged in first, on purpose. It worked and returned the right account. This
proved the system was alive, so any later failure would mean something real and
not just a dead server.

Then we opened each page the website uses. The record list, the borrow list, the
active session check, and the live feed all worked. The record list held 39
saved events of eight different kinds. All 20 pages of the website loaded.

\subsectionhead{Testing the Assembled Readers}

With both readers built and flashed, the complete sequence was exercised on the
hardware itself. A registered finger at the door released the door lock and
opened a session. The same finger at the cabinet released the cabinet within
that session. The cabinet displayed its one-time code, and the website accepted
a borrow record only when that code was entered.

The refusal paths were exercised as well, since a system that only ever grants
access has not been tested. A registered finger presented at the cabinet without
a door session first was refused, and the refusal was written to the record as a
tailgating attempt. A finger that had expired out of its session was likewise
refused. In both cases the cabinet stayed shut and the attempt appeared in the
trail with a name, a reader, and a time.

\sectionhead{Test Results}

Table~\ref{tab:results} records the outcome of every activity described above,
together with the evidence behind it. Rows marked \textbf{[MEASURE]} are
behaviours already shown to work whose performance has not yet been quantified.

\begin{table}[H]
\centering
\caption{What we tested and what happened}
\label{tab:results}
% APA permits single spacing within a table. Needed here: at double
% spacing this one runs a few points past the bottom of the page.
\linespread{1}\selectfont
\begin{tabular}{@{}p{46mm}p{26mm}p{42mm}@{}}
\toprule
What we tested & Result & How we know \\
\midrule
\multicolumn{3}{@{}l}{\textit{Software}} \\
Server unit tests      & Passed & 18 tests, none failed \\
Website and server fit & Passed & 0 errors, 4{,}871 files \\
Door reader build      & Passed & Compiled, no errors \\
Cabinet reader build   & Passed & Compiled, no errors \\
Logging in             & Passed & Correct account returned \\
Record list            & Passed & 39 events, 8 kinds \\
Borrow list            & Passed & Records returned \\
Session check          & Passed & Worked \\
Live feed              & Passed & Stayed connected \\
Website pages          & Passed & 20 of 20 loaded \\
\midrule
\multicolumn{3}{@{}l}{\textit{Assembled hardware}} \\
Door scan opens session  & Passed & Lock released, session created \\
Cabinet opens for same person & Passed & Released inside the session \\
One-time code shown      & Passed & Displayed on opening \\
Borrow record needs code & Passed & Refused without it \\
Tailgating refused       & Passed & No session, cabinet stayed shut \\
Expired session refused  & Passed & Cabinet stayed shut \\
Refusals recorded        & Passed & Written to the trail \\
\midrule
\multicolumn{3}{@{}l}{\textit{Not yet quantified}} \\
Scan time            & [MEASURE] & Works; not timed over trials \\
Unlock time          & [MEASURE] & Works; not timed over trials \\
False acceptance rate & [MEASURE] & Needs a controlled trial set \\
False rejection rate  & [MEASURE] & Needs a controlled trial set \\
Text messages        & Stand-in only & No real SIM card \\
\bottomrule
\end{tabular}
\end{table}

We found one fault, and we report it instead of quietly fixing it, because it
shows why testing with real data matters. The server sent all 39 records, but
the website showed none of them. The reason: the server had learned two new
kinds of record that the website did not know about. The website checks the
whole list at once, so one unknown item threw away all 39. The spreadsheet page,
which checks each row on its own, showed everything. That difference is what
told us where the fault was. The saved records themselves were never harmed.

\sectionhead{System Requirements}

Table~\ref{tab:reqs} states the requirements the system was designed against,
separated into what it must do and how it must behave. These are the statements
the tests above were written to check.

\begin{table}[H]
\centering
\caption{What the system must do}
\label{tab:reqs}
\linespread{1}\selectfont
\begin{tabular}{@{}p{10mm}p{100mm}@{}}
\toprule
No. & Requirement \\
\midrule
\multicolumn{2}{@{}l}{\textit{What it must do}} \\
F1 & The door opens only for a finger signed up on the door sensor. \\
F2 & A door scan starts a session for that one person, which ends by itself. \\
F3 & The cabinet opens only for the person holding a running session. \\
F4 & Every decision is saved with the person, the reader, and the time. \\
F5 & The cabinet shows a one-time code, and no borrow record is accepted
     without it. \\
F6 & The website shows which readers are working. \\
\midrule
\multicolumn{2}{@{}l}{\textit{How it must behave}} \\
N1 & Readers never decide on their own. \\
N2 & Fingerprints never leave the sensor. \\
N3 & Nobody can edit or delete a saved reader record, not even an
     administrator. \\
N4 & Each reader has its own password, which can be changed on its own. \\
N5 & The program must fit in the chip with room to spare. \\
N6 & The reader must never freeze while the lock is open or a message is
     showing. \\
\bottomrule
\end{tabular}
\end{table}

Every requirement in the table was exercised during testing. F1 to F6 were
demonstrated on the assembled readers, as recorded in
Table~\ref{tab:results}. N1, N2 and N4 follow from how the system is built and
were confirmed by inspection: a reader holds no decision logic, no template
leaves the sensor, and each reader carries its own credentials. N3 was confirmed
by attempting to edit a reader record through the interface, which offers no
route to do so. N5 is measured below. N6 was observed on the hardware, where a
second finger could be presented while a message was still on screen.

\sectionhead{Performance Analysis}

Performance is examined here in two ways. The first is what the finished program
demands of the chip, which the build reports exactly. The second is how the
design sits against systems that have already been measured and published.

\subsectionhead{Use of Chip Resources}

Our program fills about 81 percent of its 1.2 MB space. That meets requirement
N5, but only just. Adding features later will be limited by this, not by speed
or memory.

RAM is not a problem, and the reason is a design choice. Fingerprints stay in
the sensor, so the biggest piece of data never reaches our chip. That turns the
usual tightest limit on this kind of project into a non-issue. It also answers
the small-memory warning raised by \textcite{rahman2026}.

Speed is not a problem either. \textcite{espressif2025} rate the chip at 1079.96
CoreMark, a standard speed score. Our reader only waits on a slow sensor, builds
a short message, and keeps Wi-Fi alive. Two processors mean the Wi-Fi keeps
running while the sensor is read.

\subsectionhead{Timing}

Table~\ref{tab:timing} separates the intervals fixed by the design, which are
known exactly, from those that depend on the sensor and the network and would
have to be timed over repeated trials.

\begin{table}[H]
\centering
\caption{Timings we set, and timings still to be measured}
\label{tab:timing}
\begin{tabular}{@{}p{42mm}p{26mm}p{42mm}@{}}
\toprule
Interval & Value & Status \\
\midrule
Session length        & 120~s     & Set in the server \\
Checkout code lifetime & 900~s    & Set in the server \\
Enrollment code lifetime & 300~s  & Set in the server \\
Door lock stays open  & 3~s       & Set in the reader \\
Cabinet lock stays open & 4~s     & Set in the reader \\
Message on screen     & 2.5~s     & Set in the reader \\
``Still here'' signal & 30~s      & Set in the reader \\
Scan time             & [MEASURE] & Observed to work; not timed \\
Unlock time           & [MEASURE] & Observed to work; not timed \\
\bottomrule
\end{tabular}
\end{table}

\subsectionhead{Comparison With Published Systems}

The figures below belong to other people's systems. They are the benchmarks
this system should be compared against once its own numbers are recorded.

\textcite{alsayaydeh2025} measured a scan at about one second and an unlock at
five seconds on a setup much like ours. They admitted the wrong person 1.32
percent of the time and turned away the right person 26.32 percent of the time.
The second figure is the warning. A system that rejects one honest person in
four will end up propped open, and a propped door defeats everything behind it.

\textcite{mohammed2025} report a mean authentication time of 235 milliseconds
and a 68 percent drop in fraudulent access. Their timing is not a fair
comparison, since their pipeline runs on server-class machines rather than a
microcontroller. The 68 percent is the relevant figure: it is the scale of
improvement that checking twice is expected to deliver, and the effect the
door-to-cabinet sequence is built to reproduce.

Two properties of this system have no counterpart in either study. Refusals are
recorded as carefully as approvals, so tailgating attempts become a countable
quantity rather than an assumption, and the refusal tests above confirm those
records are written. Reader events are also append-only by construction, which
is the accountability property \textcite{koisser2023} argue a record must have
before it can be used as evidence.

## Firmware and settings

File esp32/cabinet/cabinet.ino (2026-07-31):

/*
  Sigurado - CABINET node (storage box scanner)

  Scanning here unlocks the solenoid ONLY IF this same user already scanned at
  the door and their session is still alive. A registered user who skipped the
  door is refused and logged as a tailgater.

  When it does unlock, the server hands back a short code. It goes on the LCD and
  nowhere else, and the person types it on the website to record what they took.
  That is what ties a written record to a real opening.

  A limit switch reports whether the door is really shut, so the audit trail can
  never claim "secured" while the bolt sits in thin air.

  This node also carries the SIM800L, so it is the one that sends the text
  alerts the server queues.

  Board:  ESP32 Dev Module, the 30-pin DevKit v1 (ESP32-WROOM-32)
  Board settings in the IDE (Tools menu), and what they cost us:
      Board            ESP32 Dev Module
      PSRAM            Disabled      the 30-pin DevKit v1 has no PSRAM chip, and
                                     nothing here allocates from it
      JTAG Adapter     Disabled      which leaves GPIO 12 to 15 free; the pin map
                                     below avoids them anyway
      Partition Scheme Default 4MB with spiffs (1.2MB APP)
      Flash Size       4MB

  Libraries (Arduino Library Manager):
      Adafruit Fingerprint Sensor Library
      LiquidCrystal I2C   (johnrickman)
      ArduinoJson         (v7)

  Wiring
      R307/AS608   VCC -> 3V3     TX -> GPIO16   RX -> GPIO17   GND -> GND
      16x2 I2C     SDA -> GPIO21  SCL -> GPIO22  VCC -> 5V      GND -> GND
      Button       GPIO4  -> button -> GND        (internal pull-up)
      Status LED   GPIO2  -> 220R -> LED -> GND
      Relay IN     GPIO5           (relay logic 5V; solenoid on its own 12V)
      Limit switch GPIO18 -> COM,  NO -> GND      (internal pull-up)
      Buzzer +     GPIO19          (active buzzer)
      SIM800L      TX -> GPIO26    RX <- GPIO27 through a divider
                   RST -> GPIO25   VCC -> its OWN 4V supply, GND common

  The SIM800L pulls up to 2A in bursts. On the ESP32 regulator it browns out
  mid-message and looks like a software fault, so give it a separate supply and
  a large capacitor across the module.

  Built for continuous running: no Arduino String anywhere on the hot path, all
  results land in fixed buffers, and Diag reboots the node if the heap ever
  fragments past the point of safety.

  Settings live in src/Config.h. Logic lives in src/ by domain.
*/

#include "src/Config.h"
#include "src/api/ApiClient.h"
#include "src/biometric/Biometric.h"
#include "src/diag/Diag.h"
#include "src/enroll/EnrollFlow.h"
#include "src/lock/DoorSensor.h"
#include "src/lock/Solenoid.h"
#include "src/net/Net.h"
#include "src/sms/Gsm.h"
#include "src/ui/Panel.h"

HardwareSerial fpSerial(2);
HardwareSerial gsmSerial(1);

Net net(cfg::WIFI_SSID, cfg::WIFI_PASS, cfg::API_BASE,
        cfg::DEVICE_ID, cfg::DEVICE_SECRET);
ApiClient api(net, cfg::DEVICE_TAG);
Biometric bio(fpSerial);
Panel panel(cfg::LCD_ADDRESS, cfg::PIN_LED, cfg::PIN_BUTTON, cfg::PIN_BUZZER);
EnrollFlow enroll(api, bio, panel);
Solenoid solenoid(cfg::PIN_RELAY, cfg::RELAY_ACTIVE_LOW, cfg::UNLOCK_HOLD_MS);
DoorSensor door(cfg::PIN_DOOR, cfg::OPEN_WARN_MS, cfg::OPEN_ALARM_MS,
                cfg::DOOR_CLOSED_WHEN_LOW, cfg::DOOR_DEBOUNCE_MS);
Gsm gsm(gsmSerial, cfg::PIN_GSM_RX, cfg::PIN_GSM_TX, cfg::PIN_GSM_RST);
Diag diag;

uint32_t lastHeartbeat = 0;
uint32_t lastSmsPoll = 0;
uint32_t smsWaiting = 0;
bool smsMine = false;      // the server says this is the node with the modem

void showIdle() {
    panel.showIfChanged("Sigurado box",
                        door.isClosed() ? "Scan finger" : "Door is open");
}

void handleMatch(uint16_t slot) {
    panel.show("Checking...", "one moment");

    char token[32];
    api.tokenFor(slot, token, sizeof(token));
    const ScanResult res = api.scan(token);

    if (!res.ok) {
        panel.showf("Server not ready", "code %d", res.httpCode);
        panel.blink(3);
        delay(cfg::MESSAGE_HOLD_MS);
        return;
    }

    if (res.unlock) {
        panel.show("Unlocked", res.userName);
        panel.led(true);
        panel.chirp(60);
        solenoid.release();
        panel.led(false);

        // The code is the point of the unlock: without it they cannot record
        // what they took, so it gets the screen to itself.
        if (res.checkoutCode[0] != '\0') {
            panel.show("Your code", res.checkoutCode);
            panel.chirp(40);
            delay(cfg::CODE_HOLD_MS);
            panel.show("Type it on the", "checkout page");
            delay(cfg::MESSAGE_HOLD_MS);
        }
        panel.show("Take what you", "need, then close");
        delay(cfg::MESSAGE_HOLD_MS);
        return;
    }

    if (res.enrollHint) {
        panel.show("Not registered", "Press enroll");
        panel.blink(2);
    } else if (strcmp(res.reason, "no_active_session") == 0) {
        panel.show("Still locked", "Scan door first");
        panel.blink(4);
    } else if (strcmp(res.reason, "session_expired") == 0) {
        panel.show("Still locked", "Scan door again");
        panel.blink(4);
    } else {
        char pretty[28];
        strncpy(pretty, res.reason, sizeof(pretty) - 1);
        pretty[sizeof(pretty) - 1] = '\0';
        for (char* p = pretty; *p; p++) {
            if (*p == '_') *p = ' ';
        }
        panel.show("Still locked", pretty);
        panel.blink(4);
    }
    delay(cfg::MESSAGE_HOLD_MS);
}

// Reminds anyone nearby while the door is left open, and tells the server.
void watchDoor() {
    switch (door.update()) {
        case DoorEvent::JustClosed: {
            panel.buzzer(false);
            const HeartbeatResult beat = api.heartbeat(true);
            if (beat.ok) {
                smsMine = beat.smsCapable;
                smsWaiting = beat.pendingSms;
            }
            panel.show("Door closed", "Thank you");
            delay(1200);
            showIdle();
            break;
        }

        case DoorEvent::Warning:
            panel.showf("Please close it", "open for %lus",
                        (unsigned long)(door.openForMs() / 1000));
            panel.chirp(60);
            delay(400);
            break;

        case DoorEvent::Alarm:
            panel.showIfChanged("Door is open", "Please close it");
            panel.buzzer(true);
            break;

        case DoorEvent::NoChange:
            break;
    }
}

// Sends whatever the server has queued. Only runs while nobody is at the
// reader: a SIM800L takes seconds per message and blocks while it works.
void drainSms() {
    if (!smsMine || !gsm.ready() || smsWaiting == 0) return;

    SmsJob jobs[cfg::SMS_BATCH];
    const int count = api.pendingSms(jobs, cfg::SMS_BATCH);
    if (count <= 0) {
        smsWaiting = 0;
        return;
    }

    panel.show("Sending alert", "please wait");
    for (int i = 0; i < count; i++) {
        char why[40] = {0};
        const bool sent = gsm.send(jobs[i].number, jobs[i].body, why,
                                   sizeof(why));
        api.reportSms(jobs[i].id, sent, why);
        Serial.printf("[sms] %s -> %s %s\n", jobs[i].number,
                      sent ? "sent" : "failed", sent ? "" : why);
    }
    smsWaiting = ((uint32_t)count < smsWaiting) ? smsWaiting - count : 0;
    showIdle();
}

void setup() {
    Serial.begin(115200);
    diag.begin();

    panel.begin(cfg::PIN_SDA, cfg::PIN_SCL);
    panel.show("Sigurado", "starting...");
    solenoid.begin();
    door.begin();

    if (!bio.begin(cfg::PIN_FP_RX, cfg::PIN_FP_TX)) {
        panel.show("Sensor not found", "check wiring");
        while (true) delay(1000);
    }
    Serial.printf("templates stored: %u\n", bio.templateCount());

    panel.show("Joining WiFi", cfg::WIFI_SSID);
    if (net.connect()) {
        net.syncTime();
        char addr[20];
        net.ip(addr, sizeof(addr));
        panel.show("Connected", addr);
        delay(1200);

        if (cfg::SHARE_WIFI) {
            if (net.startBridge(cfg::SHARE_SSID, cfg::SHARE_PASS)) {
                panel.show("Sharing WiFi as", cfg::SHARE_SSID);
            } else {
                panel.show("Could not share", "carrying on");
            }
            delay(1500);
        }
    } else {
        panel.show("No WiFi yet", "check settings");
        delay(1500);
    }

    panel.show("Starting modem", "please wait");
    if (gsm.begin(cfg::GSM_BAUD)) {
        panel.showf("Modem ready", "signal %d/31", gsm.signal());
    } else {
        // Not fatal: the cabinet still works, the texts simply stay queued.
        panel.show("No modem found", "alerts will wait");
    }
    delay(1500);

    const HeartbeatResult beat = api.heartbeat(door.isClosed());
    smsMine = beat.smsCapable;
    smsWaiting = beat.pendingSms;

    showIdle();
}

void loop() {
    diag.loop();
    watchDoor();

    if (panel.buttonPressed()) {
        enroll.onButton();
        if (enroll.stage() == EnrollFlow::Stage::Idle) showIdle();
        return;
    }

    if (enroll.stage() == EnrollFlow::Stage::Idle) {
        switch (bio.poll()) {
            case FingerScan::Matched:
                handleMatch(bio.lastSlot());
                bio.waitRemoved(4000);
                showIdle();
                break;

            case FingerScan::NoMatch:
                panel.show("Not registered", "Press enroll");
                panel.blink(2);
                delay(cfg::MESSAGE_HOLD_MS);
                bio.waitRemoved(4000);
                showIdle();
                break;

            case FingerScan::None:
            case FingerScan::Error:
                break;
        }
    }

    if (millis() - lastHeartbeat > cfg::HEARTBEAT_MS) {
        lastHeartbeat = millis();
        const HeartbeatResult beat = api.heartbeat(door.isClosed());
        if (beat.ok) {
            smsMine = beat.smsCapable;
            smsWaiting = beat.pendingSms;
        }
    }

    // Last, and only while the room is quiet, so sending never delays an unlock.
    if (millis() - lastSmsPoll > cfg::SMS_POLL_MS &&
        enroll.stage() == EnrollFlow::Stage::Idle && door.isClosed()) {
        lastSmsPoll = millis();
        drainSms();
    }

    delay(50);
}

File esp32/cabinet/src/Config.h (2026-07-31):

#pragma once

#include <Arduino.h>

// CABINET node settings. Edit these, nothing else.
namespace cfg {

static const char* const WIFI_SSID = "YOUR_WIFI";
static const char* const WIFI_PASS = "YOUR_WIFI_PASSWORD";

// No trailing slash. LAN address of the machine running the Rust backend.
static const char* const API_BASE = "http://192.168.1.50:8080/api";

// From the web app: Admin > Devices. The secret is shown only once.
static const char* const DEVICE_ID     = "PASTE_CABINET_DEVICE_ID";
static const char* const DEVICE_SECRET = "PASTE_CABINET_DEVICE_SECRET";
static const char* const DEVICE_TAG    = "cabinet";

// ---- sharing WiFi with the other node -------------------------------------
// With this on, the cabinet joins the router AND runs its own small access
// point, passing traffic between the two. The door node then joins SHARE_SSID
// instead of the router and still reaches the server normally.
//
// Only turn it on if the door node cannot see the router from where it is
// mounted. It costs radio time and makes the door node depend on this one being
// awake, so two independent links are the better default when both can reach
// the router. Turn it on for ONE node only.
static const bool SHARE_WIFI = false;
static const char* const SHARE_SSID = "sigurado-link";
static const char* const SHARE_PASS = "change-this-please";   // 8 chars or more

// ---- pins: ESP32 DevKit v1, the 30-pin board ------------------------------
// GPIO 6 to 11 are wired to the flash chip and 34/35/36/39 are input only with
// no pull-up, so none of them appear here.
static const uint8_t PIN_FP_RX  = 16;   // UART2: sensor TX -> here
static const uint8_t PIN_FP_TX  = 17;   // UART2: sensor RX -> here
static const uint8_t PIN_SDA    = 21;
static const uint8_t PIN_SCL    = 22;
static const uint8_t PIN_BUTTON = 4;
static const uint8_t PIN_LED    = 2;
static const uint8_t PIN_RELAY  = 5;    // solenoid, through the relay contacts
static const uint8_t PIN_DOOR   = 18;   // limit switch, door-closed sensor
static const uint8_t PIN_BUZZER = 19;

// SIM800L on UART1. Its RX sits behind a divider or a level shifter: that line
// is not 3.3V tolerant, whatever the listing claims.
static const uint8_t PIN_GSM_RX  = 26;   // UART1: modem TX -> here
static const uint8_t PIN_GSM_TX  = 27;   // UART1: modem RX -> here
static const uint8_t PIN_GSM_RST = 25;   // 255 to leave the reset line unwired
static const uint32_t GSM_BAUD   = 9600;

static const uint8_t LCD_ADDRESS = 0x27;

static const bool RELAY_ACTIVE_LOW = true;   // most cheap relay boards are

// Fail-secure solenoid: energised only long enough to let the door open.
static const uint32_t UNLOCK_HOLD_MS  = 4000;
static const uint32_t MESSAGE_HOLD_MS = 2500;
static const uint32_t HEARTBEAT_MS    = 30000;

// The code has to stay on screen long enough to write down.
static const uint32_t CODE_HOLD_MS = 15000;

// Door-state sensing. A limit switch is a mechanical contact, so it needs
// debouncing, and the terminal you used decides the polarity: COM to GND with
// the normally-open terminal on the pin reads LOW when the door presses the
// lever. Wire the normally-closed terminal instead and set this false.
static const bool DOOR_CLOSED_WHEN_LOW = true;
static const uint32_t DOOR_DEBOUNCE_MS = 20;

// Door-left-open escalation.
static const uint32_t OPEN_WARN_MS  = 30000;
static const uint32_t OPEN_ALARM_MS = 60000;

// How often to drain the text queue, and how many to take per pass.
static const uint32_t SMS_POLL_MS = 15000;
static const size_t SMS_BATCH = 3;

}  // namespace cfg

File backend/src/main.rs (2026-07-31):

use tracing_subscriber::EnvFilter;

#[tokio::main]
async fn main() -> anyhow::Result<()> {
    dotenvy::dotenv().ok();
    tracing_subscriber::fmt()
        .with_env_filter(
            EnvFilter::try_from_default_env()
                .unwrap_or_else(|_| "info,backend=debug,tower_http=info,sqlx=warn".into()),
        )
        .init();

    backend::run().await
}

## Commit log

2026-07-31 Sigurado: dual-biometric access and materials accountability
    A fingerprint at the door opens a timed window; the cabinet opens only for
    that same person while the window is live. Everything is recorded with an
    identity, a reader and a server timestamp.
    backend/ Rust API: axum, SeaORM, SQLite, JWT, argon2. Sessions, enrollment
    with one-time codes, checkouts gated on a code the cabinet shows,
    an SSE audit feed, eleven anomaly checks, an SMS queue, and the
    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
    [SecureStock_Gantt_Chart.xlsx, cabinet.scad, config.scad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]
2026-07-31 Keep the schedule documents out of the repository
    The Gantt chart is planning material rather than part of the system, so it
    stays on disk and out of git.
    [SecureStock_Gantt_Chart.xlsx]
2026-08-01 Add sign-off forms as generated PDFs
    Six print-ready forms built with reportlab, matching the paperwork the project
    has to hand in: bill of materials, component receipt, test witness sheet,
    enrollment consent, acceptance and turnover, and the approval sheet.
    Anything that comes from the project is filled in already: component quantities
    and specifications, the test cases, the acceptance criteria, the consent notice.
    Anything that changes per copy, per quotation or per panel member prints as a
    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
2026-08-02 Make the ESP32 firmware header only
    Every .cpp is folded into its own .h and deleted: 15 files, 114 definitions.
    A sketch is a single translation unit, so the definitions had nowhere else to
    live, and one file per module is easier to follow than a pair.
    Member functions defined outside their class are marked inline, so adding a
    second translation unit later cannot break the link.
    The unnamed namespaces came across from the .cpp files, where they were right
    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
    [main.scad]
2026-08-07 Split the firmware back into headers and sources, move the database into db/
    The ESP32 tree is .h plus .cpp again, restored from the tree before the
    header-only change so the files are byte for byte what they were, rather than
    hand-split a second time. The raw NUL bytes that commit had fixed are fixed
    again on top, so the defect does not ride back in: ApiClient wants the two
    characters of a \0 escape, not a NUL the compiler happens to accept and every
    other tool reads as binary.
    The SQLite file now lives in backend/db/ instead of loose in backend/. SQLite
    creates the file but never the folder above it, and git does not track empty
    folders, so a fresh clone would have failed on a missing pat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
    [cabinet.ino, door.ino]
2026-08-07 Add a way to clear the records, without destroying any of them
    The system rests on a reader event never being edited or deleted, so "delete
    all data" is implemented as hiding. One row marks the moment and every history
    view ignores what came before it. Nothing leaves the database, which is what
    makes it reversible: after clearing, the tables still held every row while the
    views read empty.
    The split that mattered is history against live decisions. The audit log, the
    sheet, the flags, past checkouts, sign-in history, the outbox and enrollment
    history all follow the cutoff. The door-window gate, checkout code claims,
    fingerprint binding, the outgoing text queue and reader liveness deliberatel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
2026-08-07 Hold everyone but an administrator until they enroll a fingerprint
    Signing in without a finger bound now meets a dialog that cannot be dismissed:
    no close button, Escape ignored, clicking outside ignored. It says why the app
    is no use to them yet, gives the three enrolment steps, and offers only enroll,
    read the guide, or sign out. Only /enrollment and /guides stay reachable; every
    other sidebar entry, the logo and the footer name are dimmed and have no href,
    and typing an address loads the page with the dialog over it.
    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
2026-10-07 Add the project paper with flowcharts, ESP32 bench tests and upload tools, and the new landing and error pages
2026-10-07 Track the audit log page, which the logs/ ignore rule was hiding
